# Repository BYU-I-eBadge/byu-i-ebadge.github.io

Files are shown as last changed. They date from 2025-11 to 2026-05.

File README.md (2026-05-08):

# BYU-I e-Badge Project
Github Pages for the BYU-I e-Badge Project

[e-Badge Project Repository](https://github.com/BYU-I-eBadge/e-badge)
- [e-Badge Pinouts](https://github.com/BYU-I-eBadge/e-badge/blob/main/docs/Pinout.md)

[Minibadge Project Repository](https://github.com/BYU-I-eBadge/minibadge)

## Tutorials:
## WebFlasher:
This allows flashing the board directly from a webpage:
- [WebFlash](https://byu-i-ebadge.github.io/namebadge-webflash/)

### Minibadge Tutorials:
- [LED Tutorial](/minibadge_tutorial/tutorial)
- [I2C Tutorial](/minibadge_tutorial_i2c/tutorial) (Todo)
- [Old Tutorial](/minibadge_tutorial_old/tutorial)

#### Tutorial Minibadges:
- [Example Minibadges](https://github.com/BYU-I-eBadge/byu-i-ebadge.github.io/tree/main/minibadge_examples/)
    - [LED Tutorial Minibadge](https://github.com/BYU-I-eBadge/byu-i-ebadge.github.io/tree/main/minibadge_examples/LED)
    - [I2C Tutorial Minibadge](https://github.com/BYU-I-eBadge/byu-i-ebadge.github.io/tree/main/minibadge_examples/I2C)

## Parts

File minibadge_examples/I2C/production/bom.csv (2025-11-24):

Designator | Footprint | Quantity | Value | LCSC Part #
MB1 | MiniBadge_Full | 1 | MiniBadge_Full
U1 | DIP-8_L10.0-W6.5-P2.54-LS7.6-BL-A | 1 | AT24C02C-PUM | C8810

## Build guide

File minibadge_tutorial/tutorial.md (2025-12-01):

# Minibadge Tutorial

This tutorial is designed for KiCad 9.0.4.
Download the latest version of KiCad from [kicad.org](https://www.kicad.org/download/).
A KiCad configuration with metric unit settings is assumed.

## Download Minibadge Symbols and Footprints

The Minibadge follows a standard which can be accessed as a set of KiCad libraries for footprints and schematics.

To obtain the files necessary to build your Minibadge, navigate to [github.com/BYU-I-eBadge/minibadge/releases](https://github.com/BYU-I-eBadge/minibadge/releases).

The KiCad symbol and footprint variants can be found on the releases page. On the latest release[^1], download `minibadge_full.kicad_sym` and `MiniBadge_Full.kicad_mod` for this tutorial. Save these in a folder that can be navigated to later.

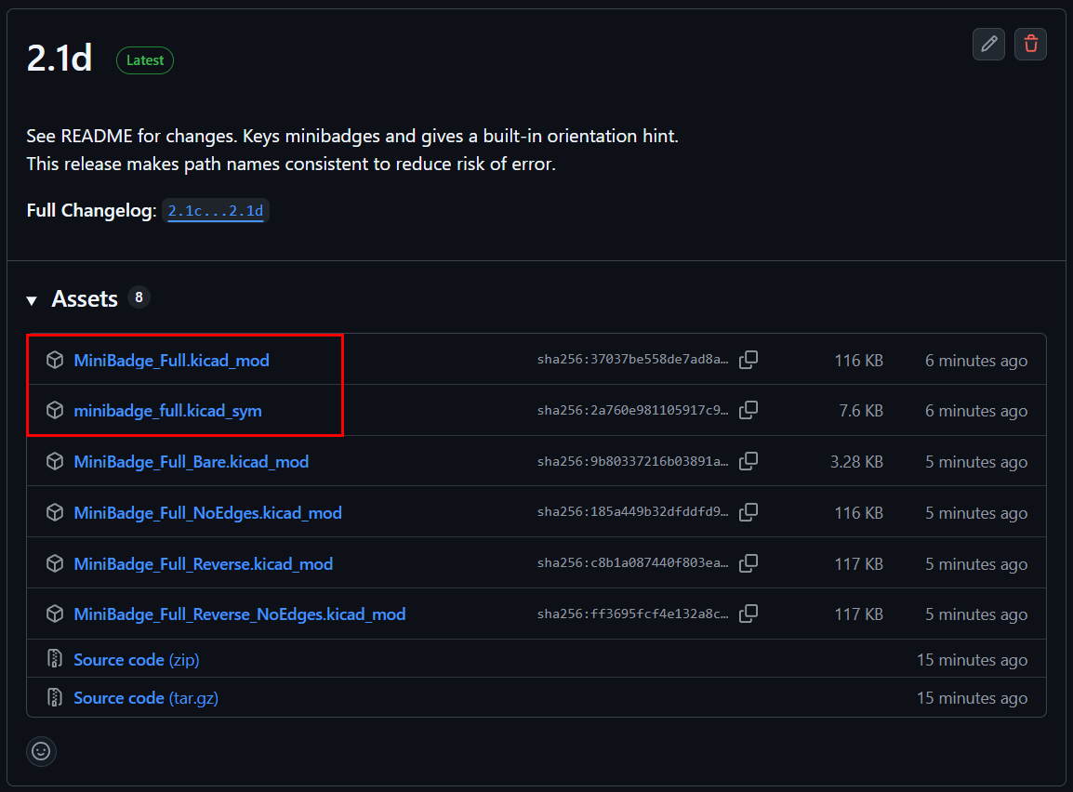
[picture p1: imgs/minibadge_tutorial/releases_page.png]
minibadge release


## Design in KiCad

### Initial Project Setup

Make and open a new project in KiCad. Save it in a directory of your choice. Feel free to name the project something memorable.

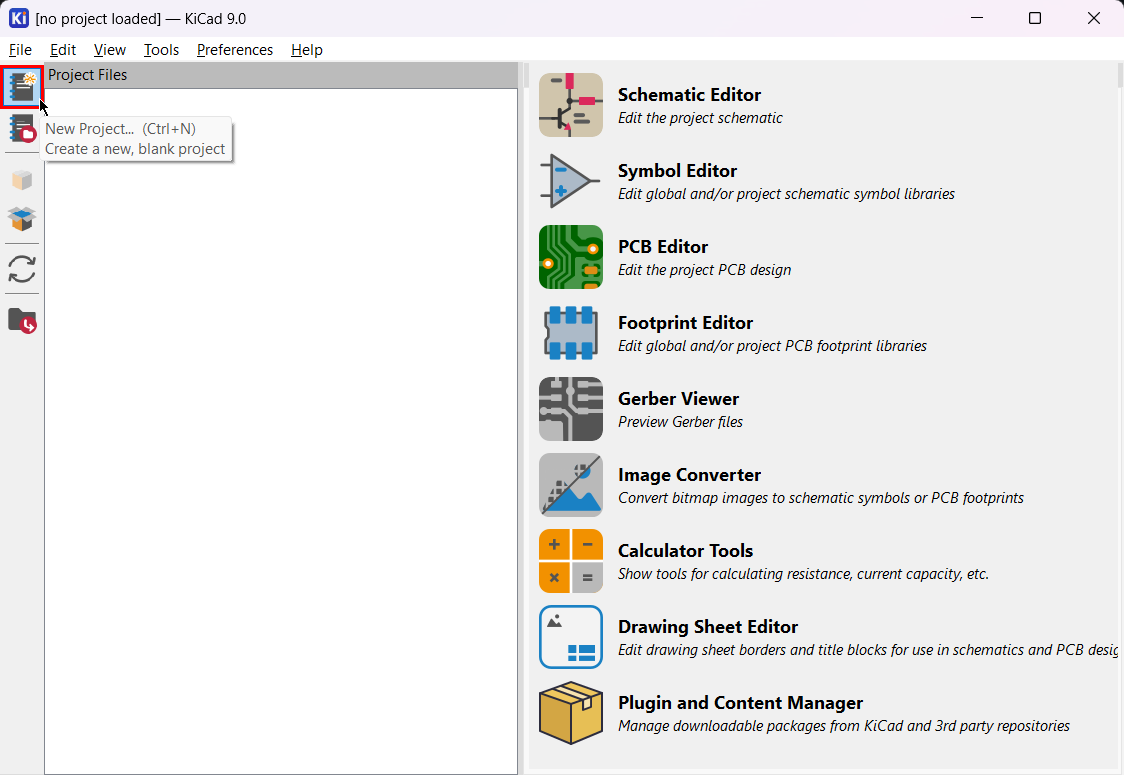
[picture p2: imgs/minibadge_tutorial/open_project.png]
hint make new project


After making your project, the window should now look something like this:

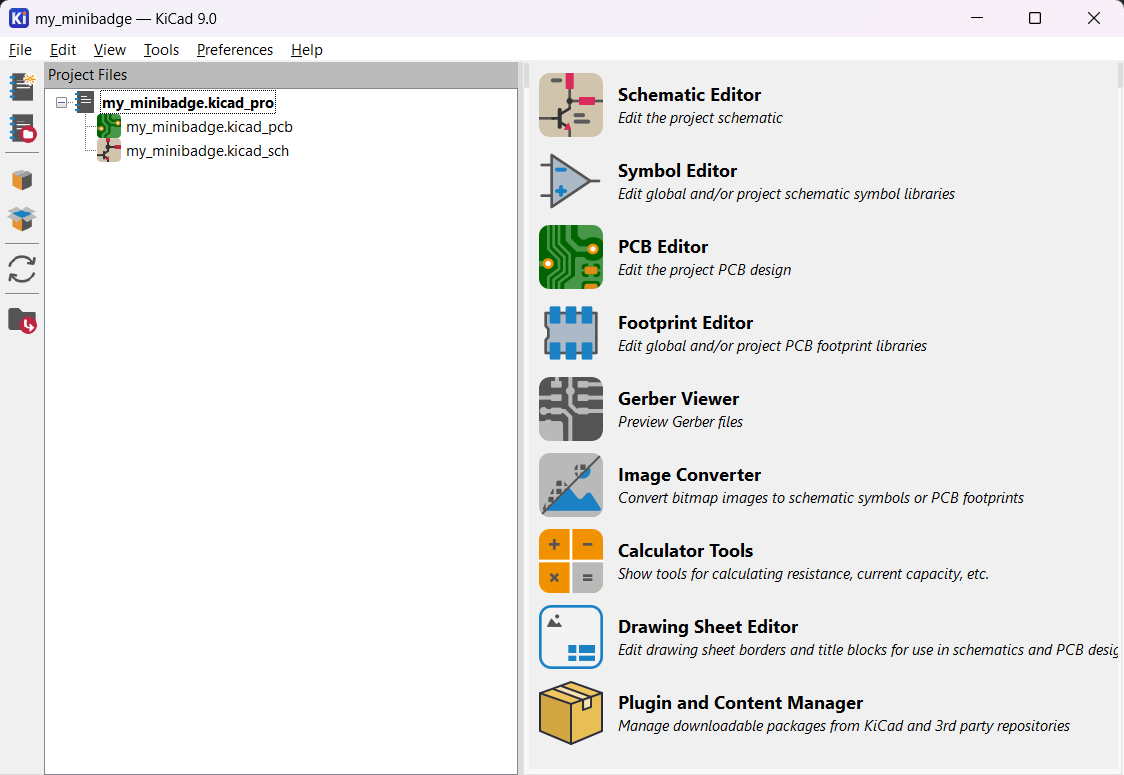
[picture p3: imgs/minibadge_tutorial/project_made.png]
created project


Now that the project has been made, the symbol and footprint need to be added so they are accessible from library browsers. Move the downloaded files into your project folder or somewhere easily accessible.

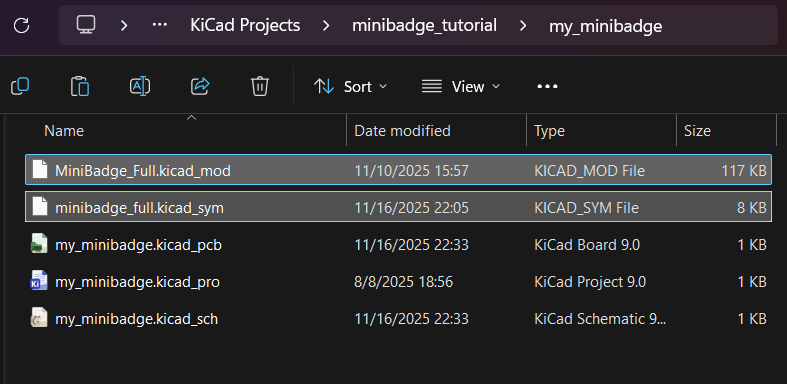
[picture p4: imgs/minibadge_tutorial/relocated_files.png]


Navigate to `Preferences` on the toolbar.

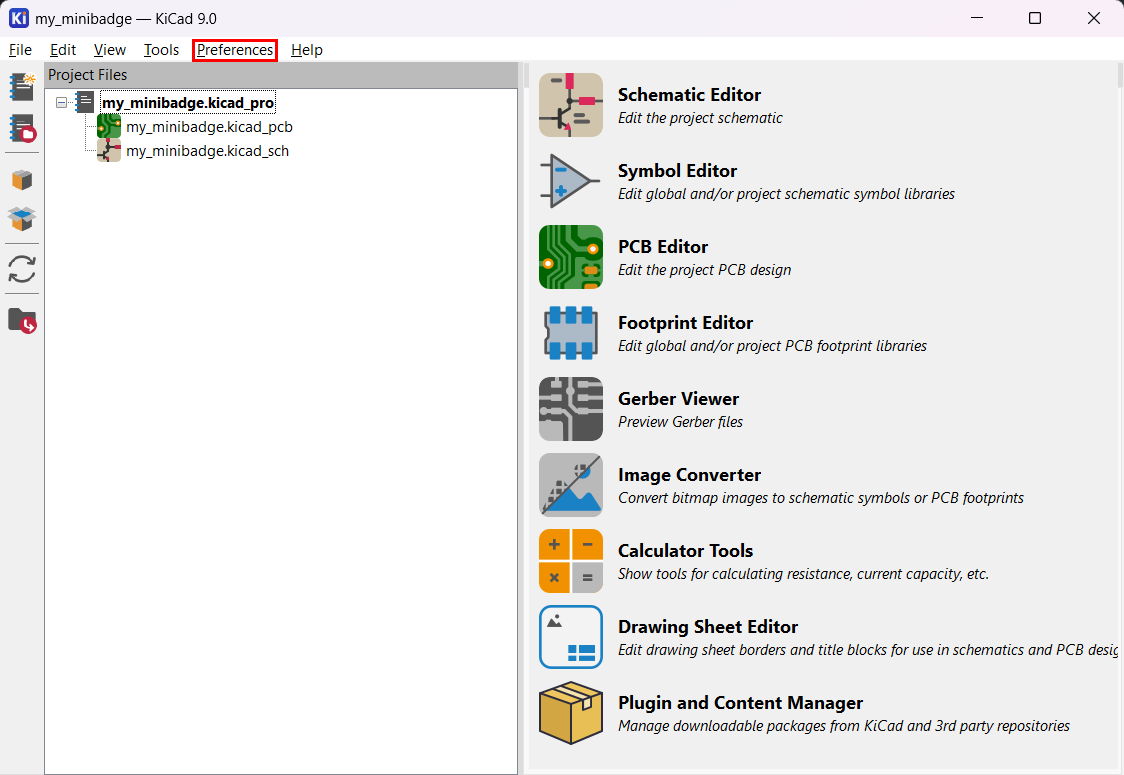
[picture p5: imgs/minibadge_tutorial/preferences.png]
go to preferences


Then, go to `Manage Symbol Libraries`.

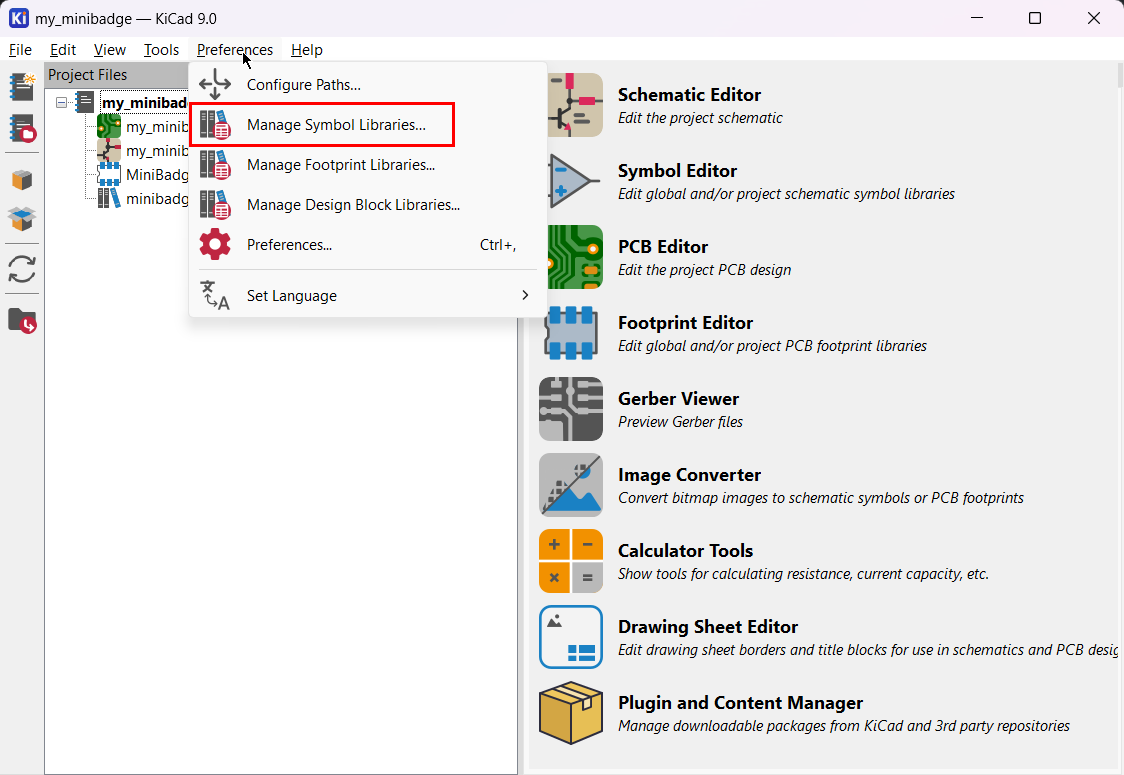
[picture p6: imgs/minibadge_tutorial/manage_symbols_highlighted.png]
go to manage symbol libraries


A new window will appear. Navigate to the `Project Specific Libraries` tab to add the Minibadge symbol to this project only.

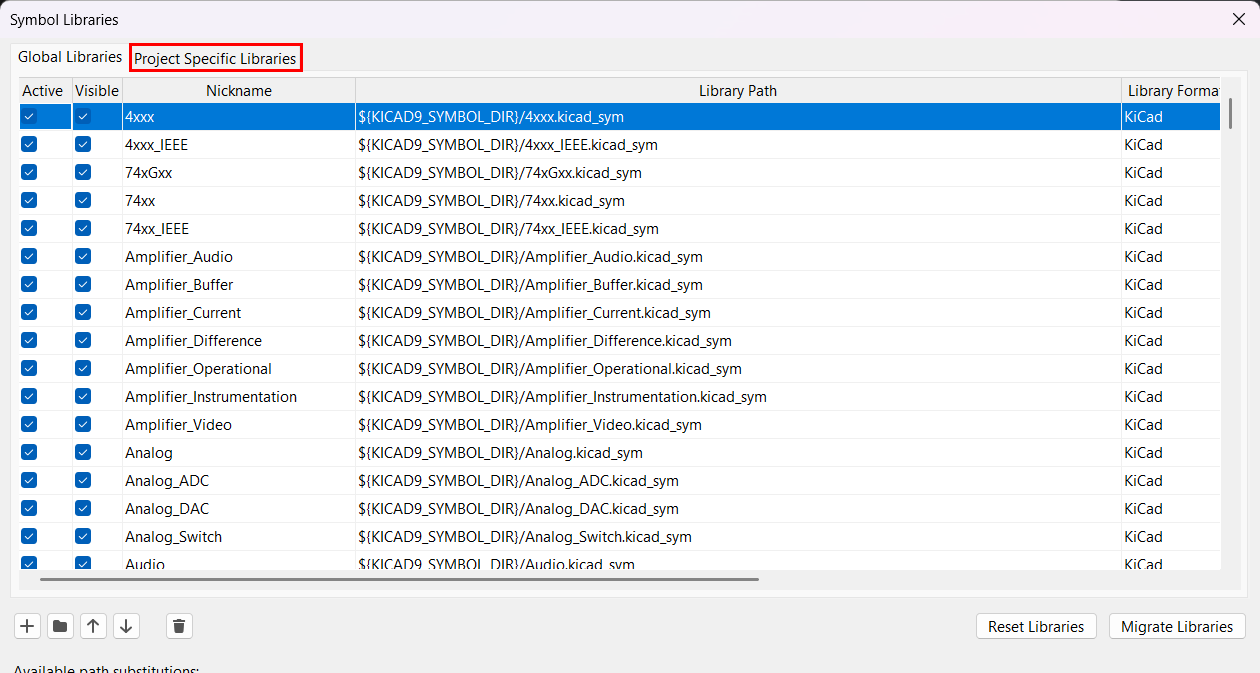
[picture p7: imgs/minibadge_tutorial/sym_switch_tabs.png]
switch tabs


Once switched to the correct tab, click the button with the folder icon to open the downloaded symbol library.
**For KiCad symbols, open the `*.kicad_sym` file to add the library.**

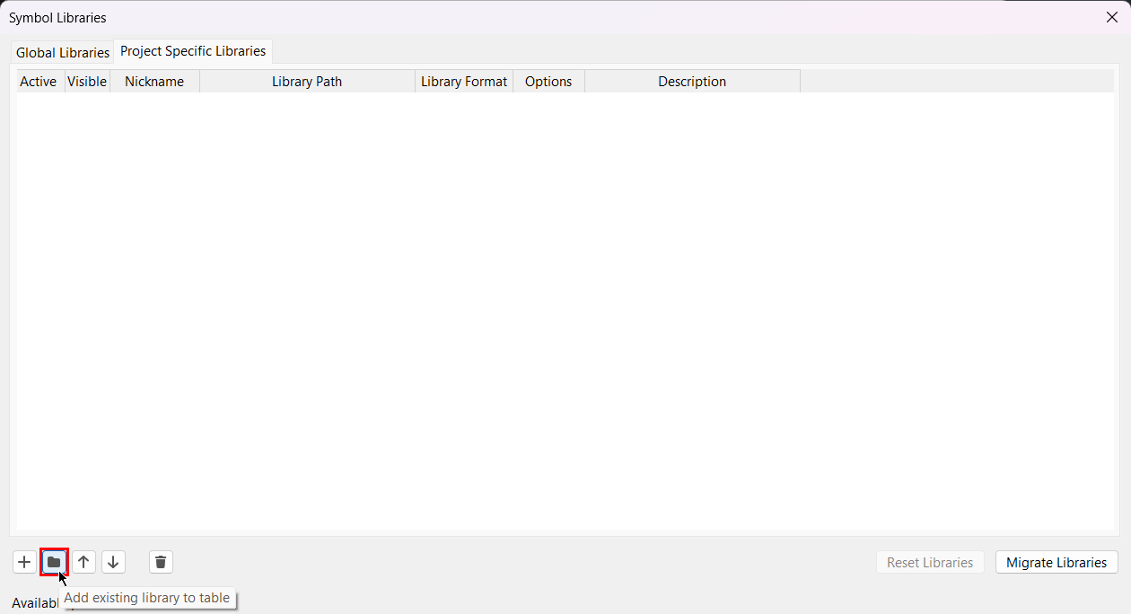
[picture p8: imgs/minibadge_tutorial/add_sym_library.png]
add symbol library button


Select the `minibadge_full.kicad_sym` file from the folder it was stored in and open it.

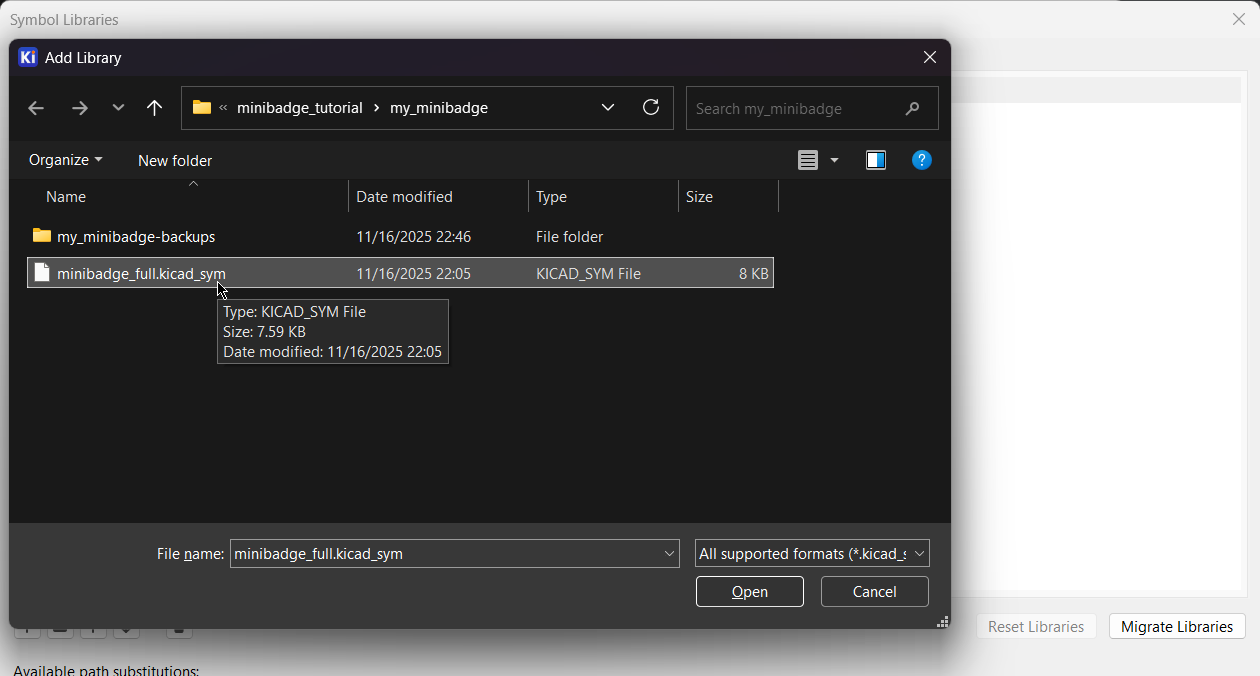
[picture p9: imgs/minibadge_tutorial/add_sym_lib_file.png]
add symbol library file


Next, to avoid any pathing related errors, rename the library Nickname from "minibadge_full" to "Minibadge" (case-sensitive).

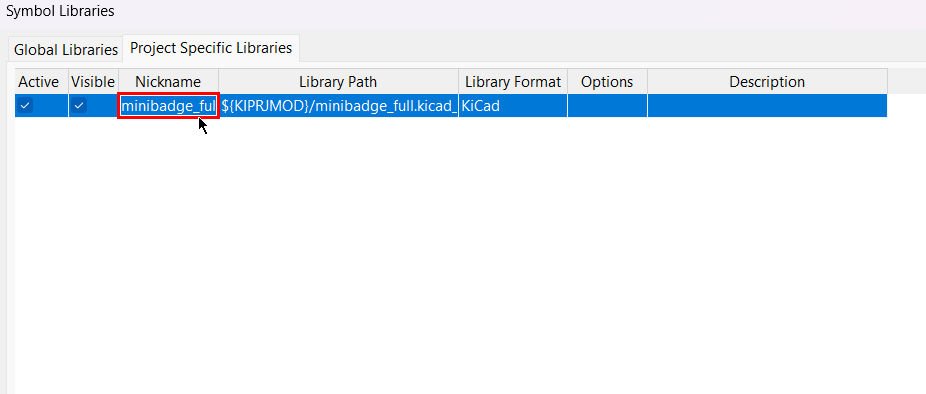
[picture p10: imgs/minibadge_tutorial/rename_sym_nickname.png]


The Symbols Library Window should now look something like this:

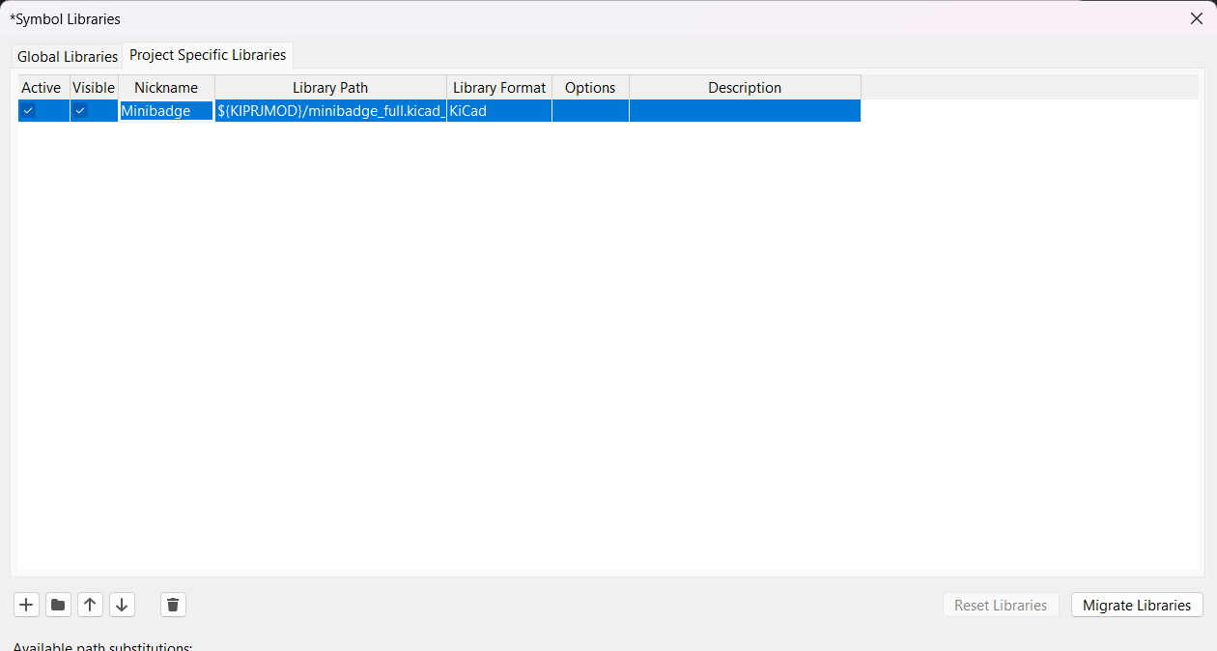
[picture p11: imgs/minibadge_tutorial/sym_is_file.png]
point out symbol libraries are files


Press OK to save changes and close the window for managing symbol libraries. It may take a moment for the library to load into the project.

In preferences again, navigate to manage footprint libraries.

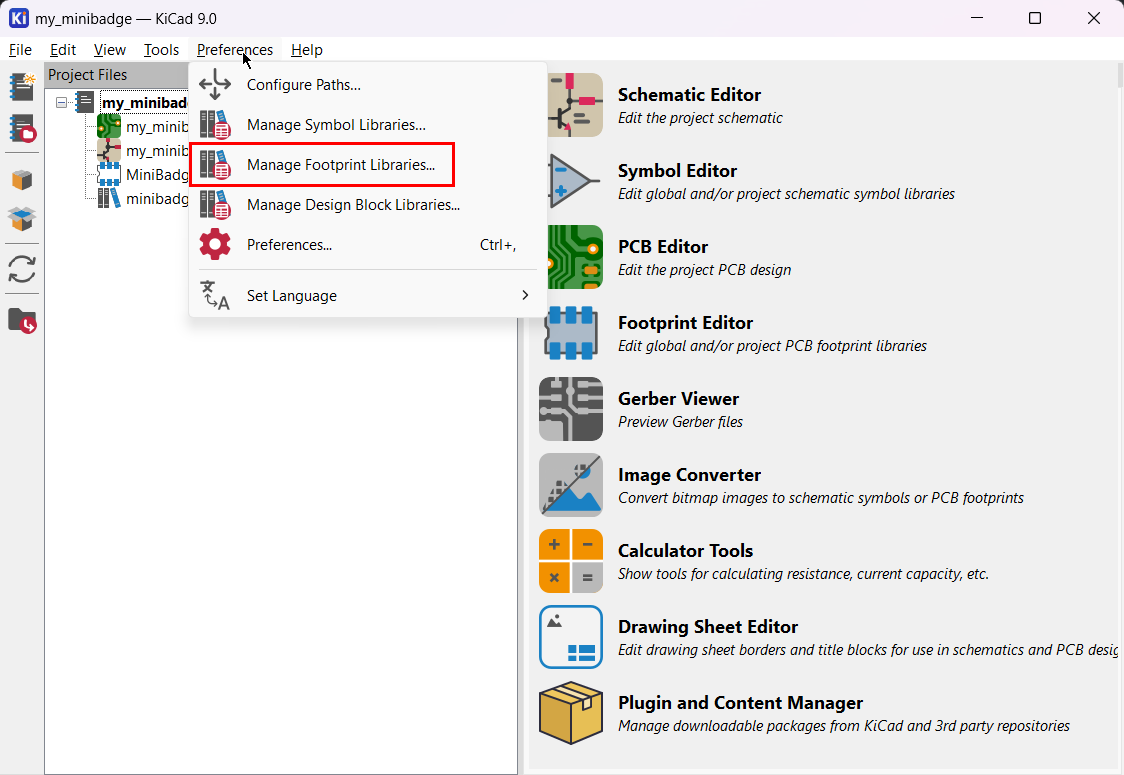
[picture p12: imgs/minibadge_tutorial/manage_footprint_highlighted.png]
go to manage footprint libraries


Similar to the window for managing symbol libraries, navigate to the `Project Specific Libraries` tab.
Click the button with the folder icon to open the downloaded footprint library.
**For KiCad footprints, open the folder that contains `*.kicad_mod` file(s) to add the library. This can reside in the same directory as your symbol library and other files; KiCad will only inventory the `*.kicad_mod` files from the selected folder.**

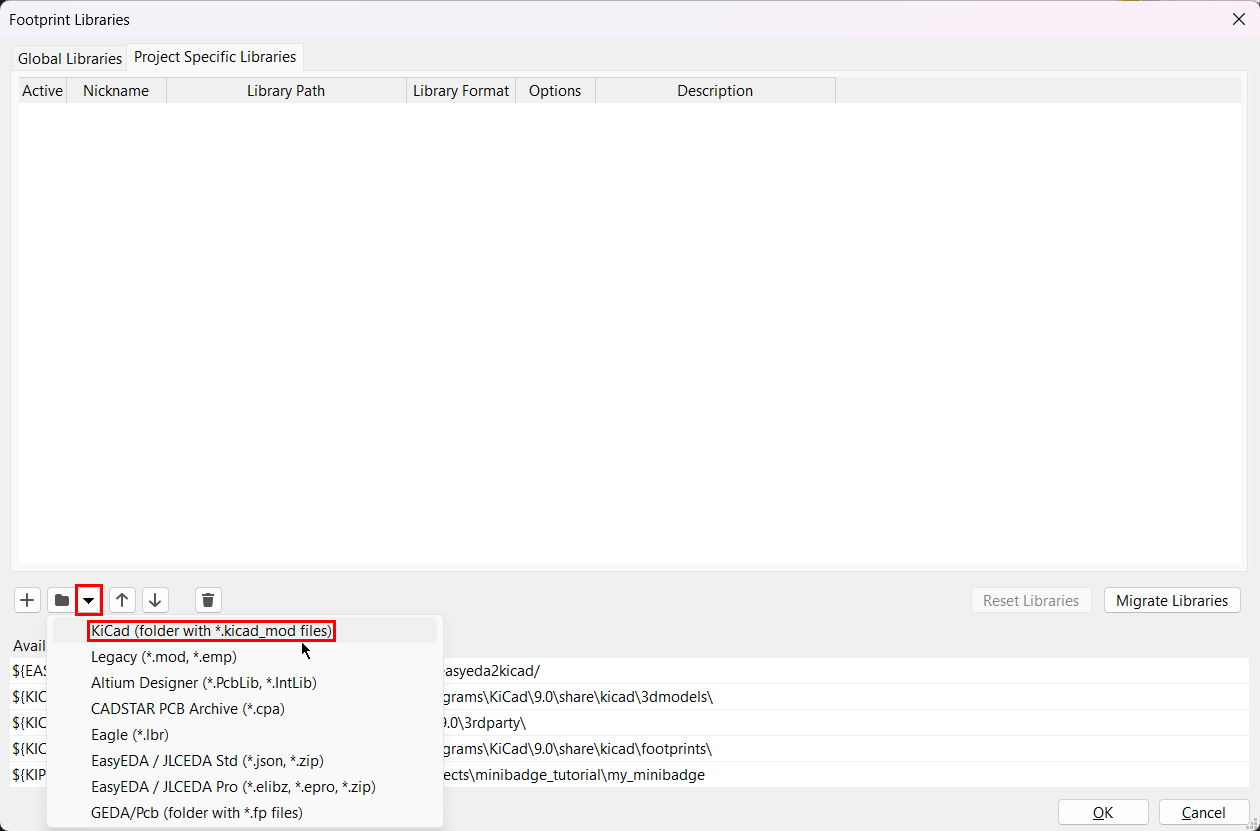
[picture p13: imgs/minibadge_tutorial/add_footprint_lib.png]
add footprint library button


Navigate to the folder which contains the `MiniBadge_Full.kicad_mod` file and click on the "Select Folder" button or any equivalent for your operating system.

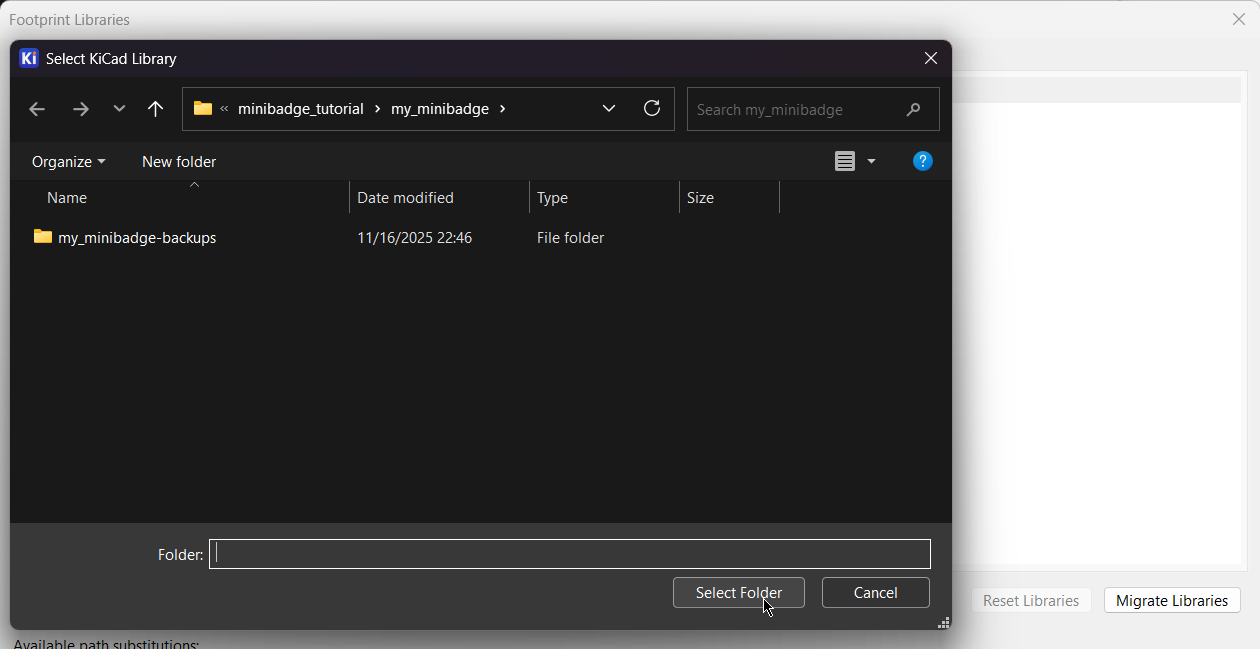
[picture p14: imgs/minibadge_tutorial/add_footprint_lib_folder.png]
add footprint library folder


Once again, change the Nickname to `Minibadge` (case-sensitive).

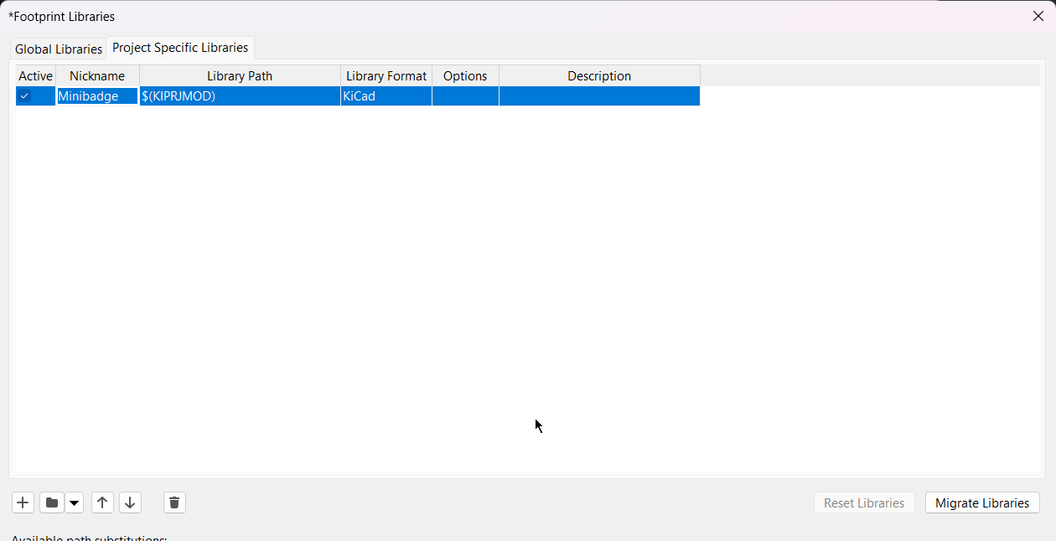
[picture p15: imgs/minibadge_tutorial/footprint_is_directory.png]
point out footprint libraries are folders


You can now press the OK button and return to the main project window.

### Schematic

Now we are ready to build the circuit with the installed libraries.

Enter the schematic editor by pressing the icon in the main window.

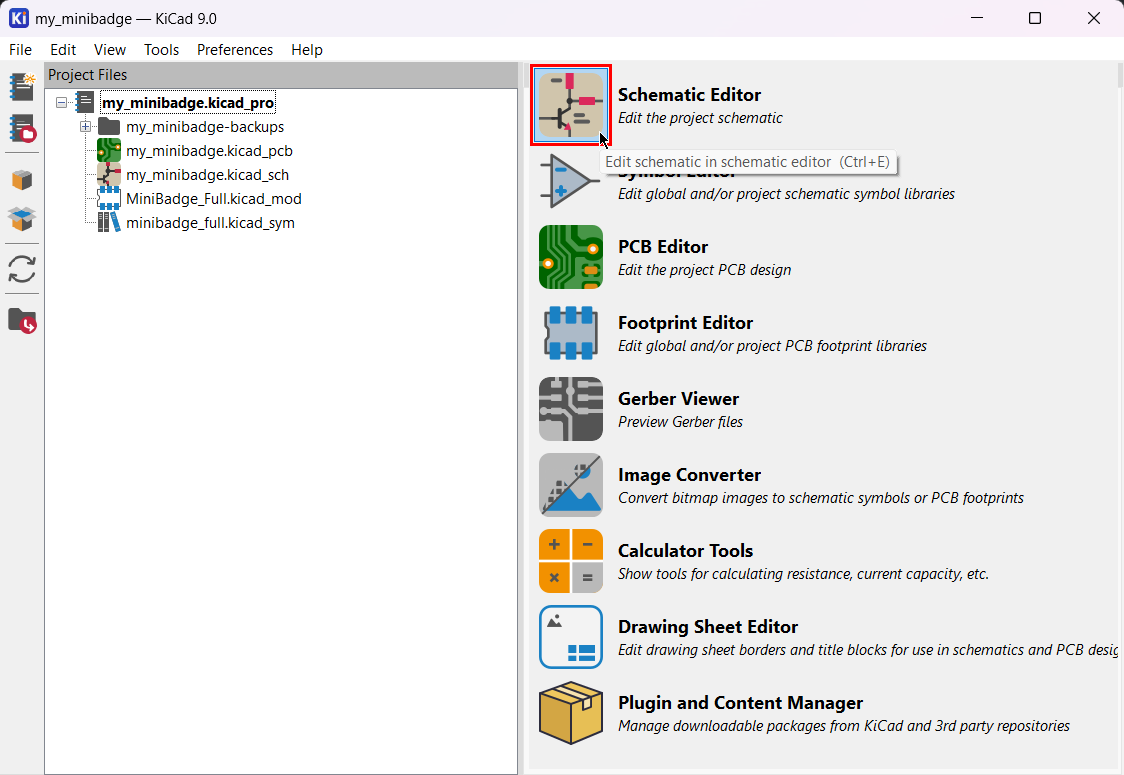
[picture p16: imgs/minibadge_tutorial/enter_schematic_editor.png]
hint enter schematic editor


A blank schematic will be shown. Start by placing symbols by pressing the highlighted icon or using the shortcut (A).

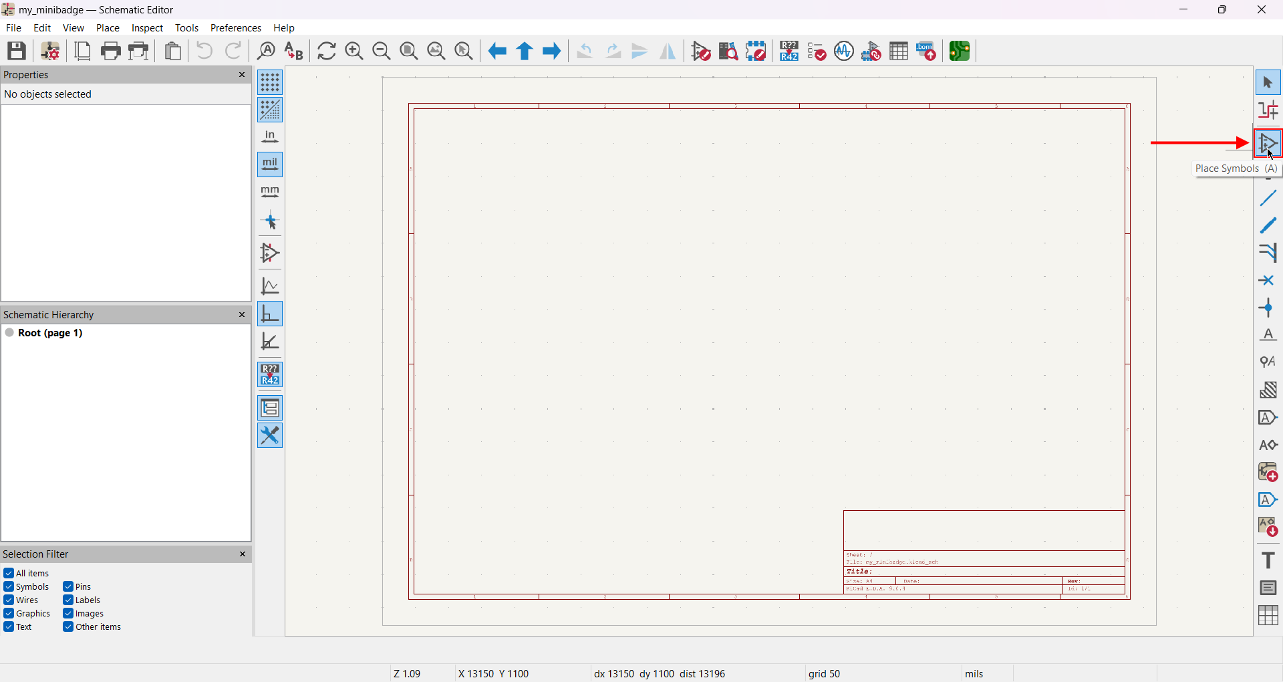
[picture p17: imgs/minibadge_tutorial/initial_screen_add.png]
initial screen hint add symbol


It may take a moment for the symbols to load. A new window will appear that will allow for selecting symbols for components.
Search for the minibadge symbol that was downloaded. Select the one that looks like the one pictured, and press OK to close the window.

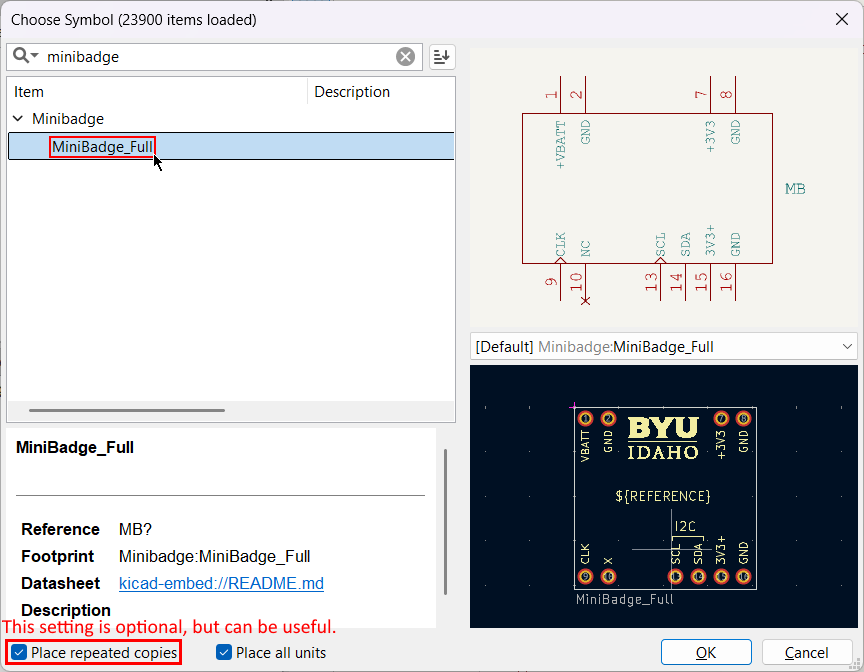
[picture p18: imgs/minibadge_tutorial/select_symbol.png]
select symbol window minibadge example


The symbol should appear attached to your cursor. Click to place the symbol. If the symbol still appears to follow your cursor after placement, press the ESC key to release your cursor; this is a side effect of having `Place repeated copies` selected.

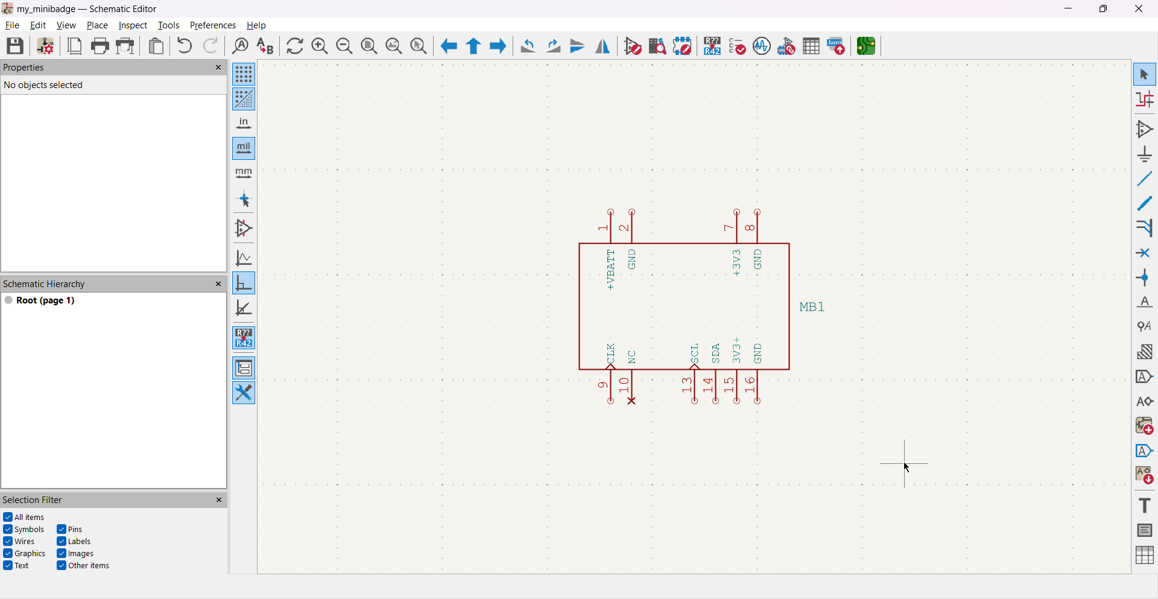
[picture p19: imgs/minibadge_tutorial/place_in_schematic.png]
symbol on schematic


For this tutorial, we will design a basic minibadge that has a simple LED circuit.
Add symbols for an LED and resistor to the schematic by following a process similar to placing the minibadge.

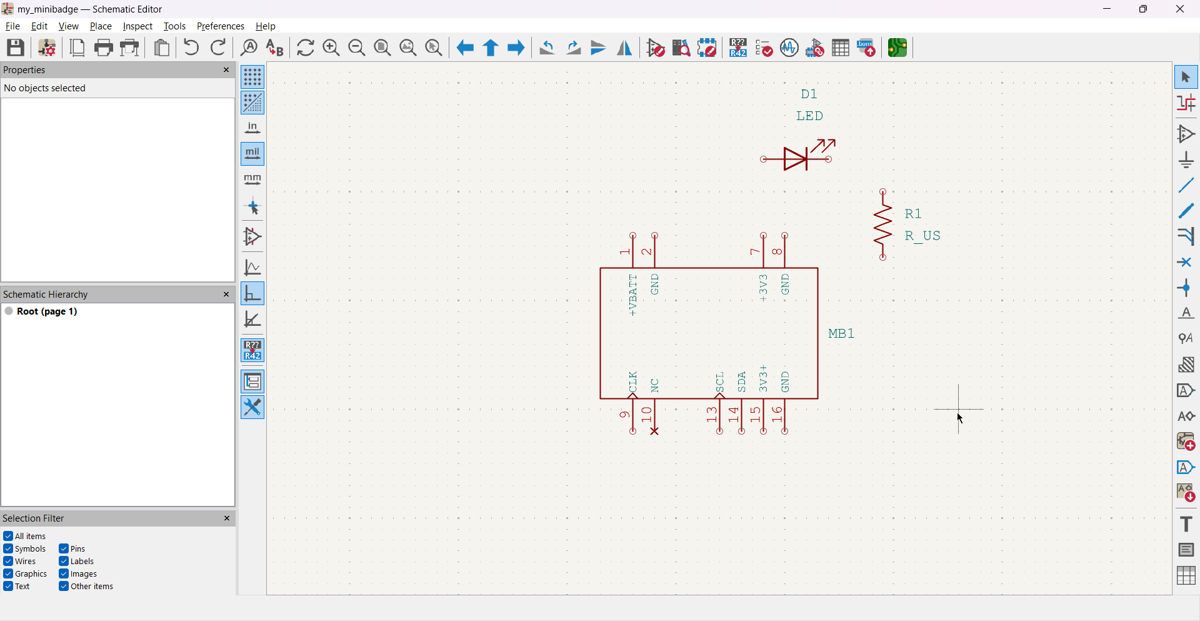
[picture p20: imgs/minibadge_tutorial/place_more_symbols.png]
add additional symbols


By double clicking on the resistor, the value can be changed. For this tutorial, the desired resistance is 100Ω, so in the "value" field, "R_US" can be replaced with 100ohm as shown below. Afterwards, press OK.

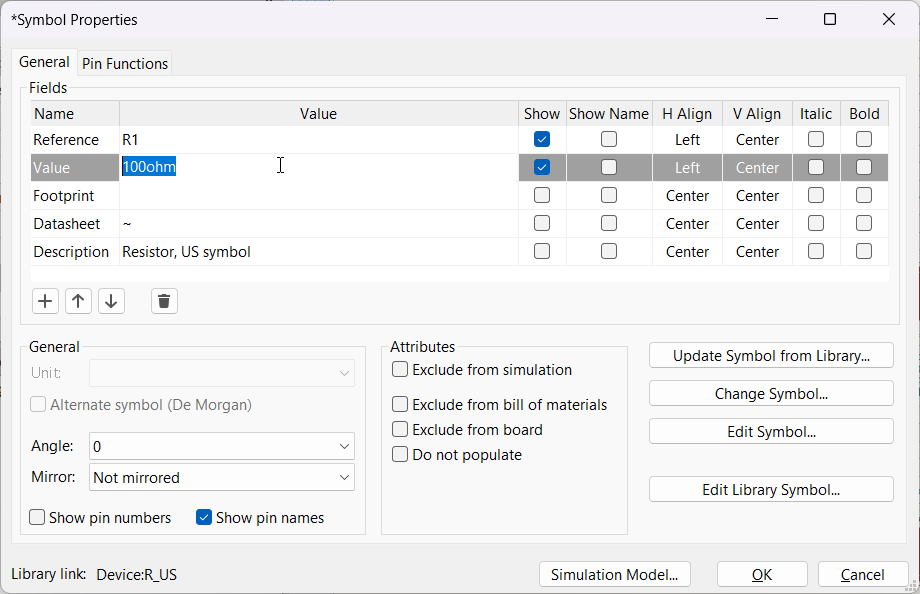
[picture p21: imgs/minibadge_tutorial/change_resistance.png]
change resistance


Now that all the symbols are placed, wires need to be added to connect the symbols together. To draw wires, press the highlighted wire button or press the (W) key.

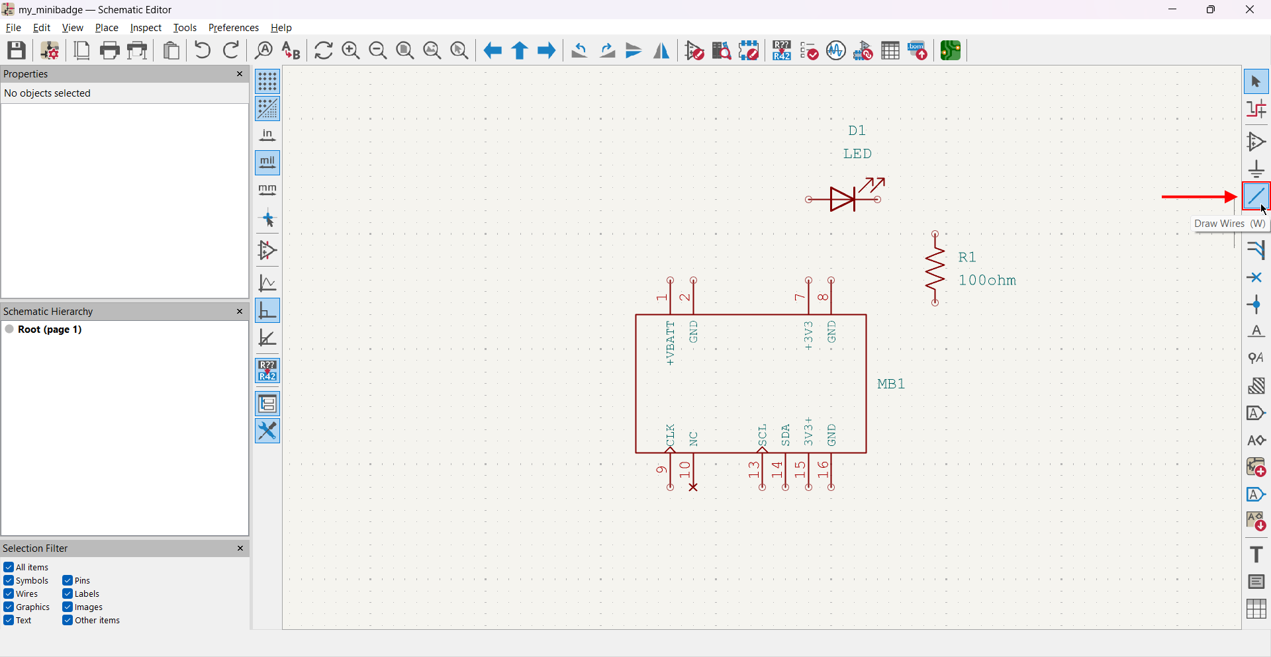
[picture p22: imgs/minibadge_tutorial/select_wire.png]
add wire


Wire the LED anode (the side with the triangle base) to any `+3V3` pin on the minibadge symbol.

Wire the LED cathode (the side with the flat line) to any side of R1.
Wire the unconnected side of R1 to any GND pin of the minibadge symbol.

**It is important that the circuit in your schematic is correct. It is easier to correct schematic issues before starting PCB design, rather than after.**

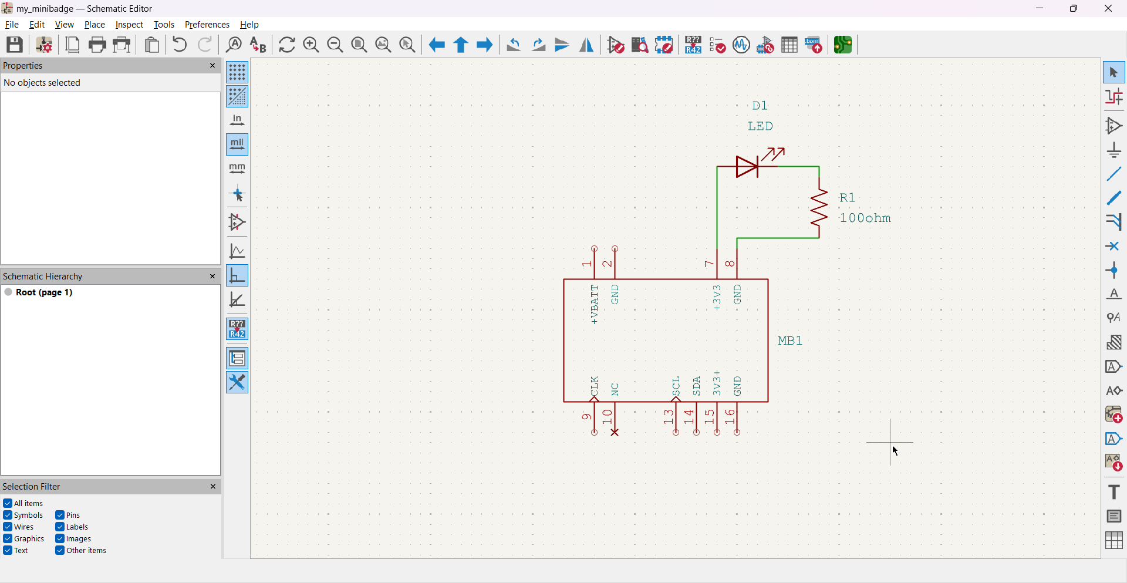
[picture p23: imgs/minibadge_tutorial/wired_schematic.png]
wired schematic


For completeness, the circuit should have its used power paths (3.3V, Ground) labeled and attached to the schematic.
Click on the icon to place power symbols or use the shortuct (P).

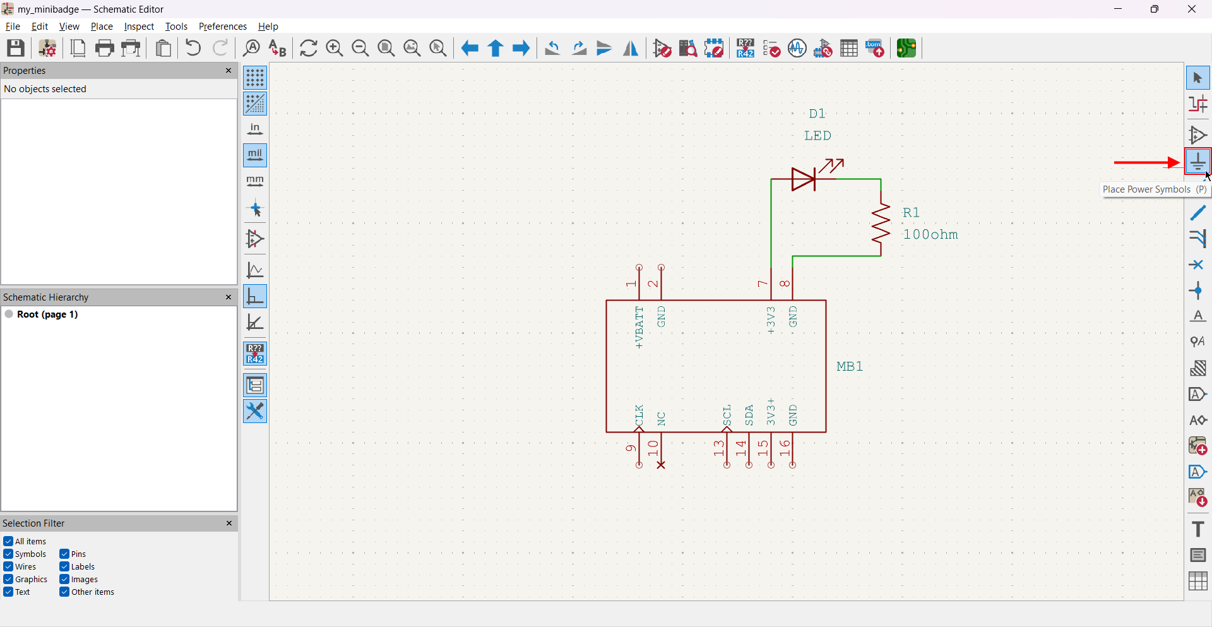
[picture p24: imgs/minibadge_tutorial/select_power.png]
add power symbols


A window will appear that operates identically to the window for picking component symbols.
For our ground (0V), use the `GND` symbol. Every pin that says `GND` on the minibadge should connect to one of these.

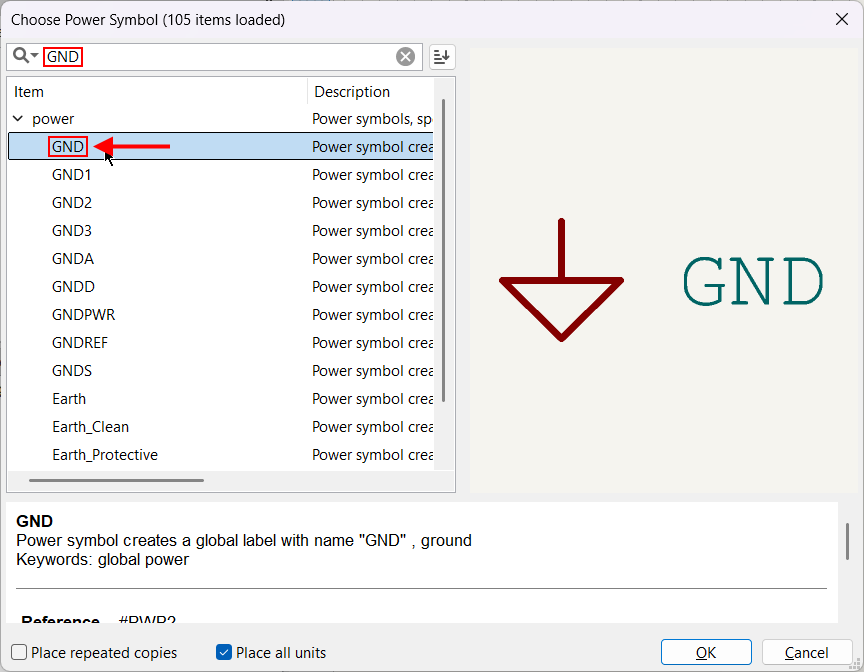
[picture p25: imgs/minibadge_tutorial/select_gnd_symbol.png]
select ground symbol window


Similarly, power symbols should be placed for 3.3V. These should go on the pins labelled `3V3+` and `+3V3`.

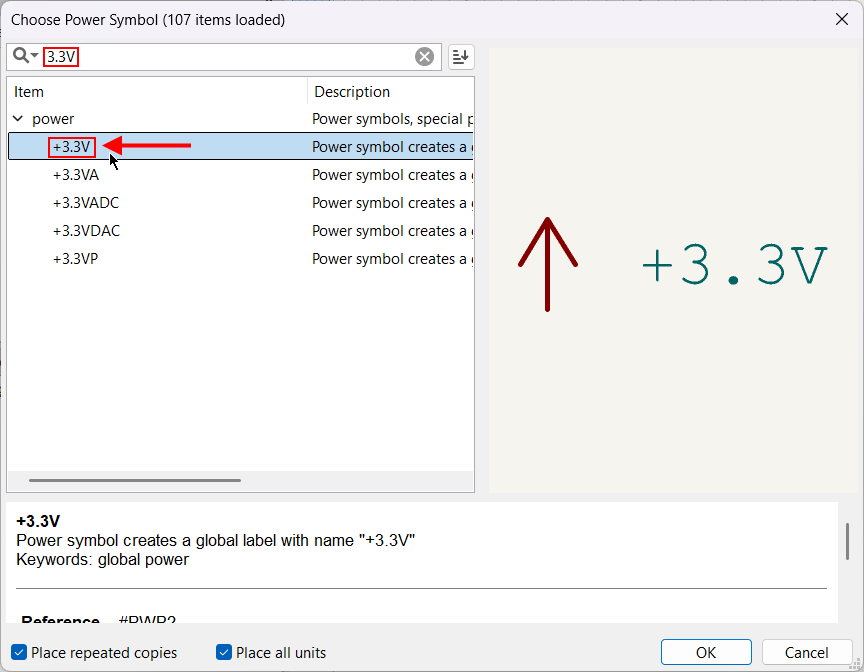
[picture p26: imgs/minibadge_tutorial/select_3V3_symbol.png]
select 3.3V symbol window


The schematic design is nearly complete. Click on the icon to place "no connect flags" on the remaining unused minibadge pins.

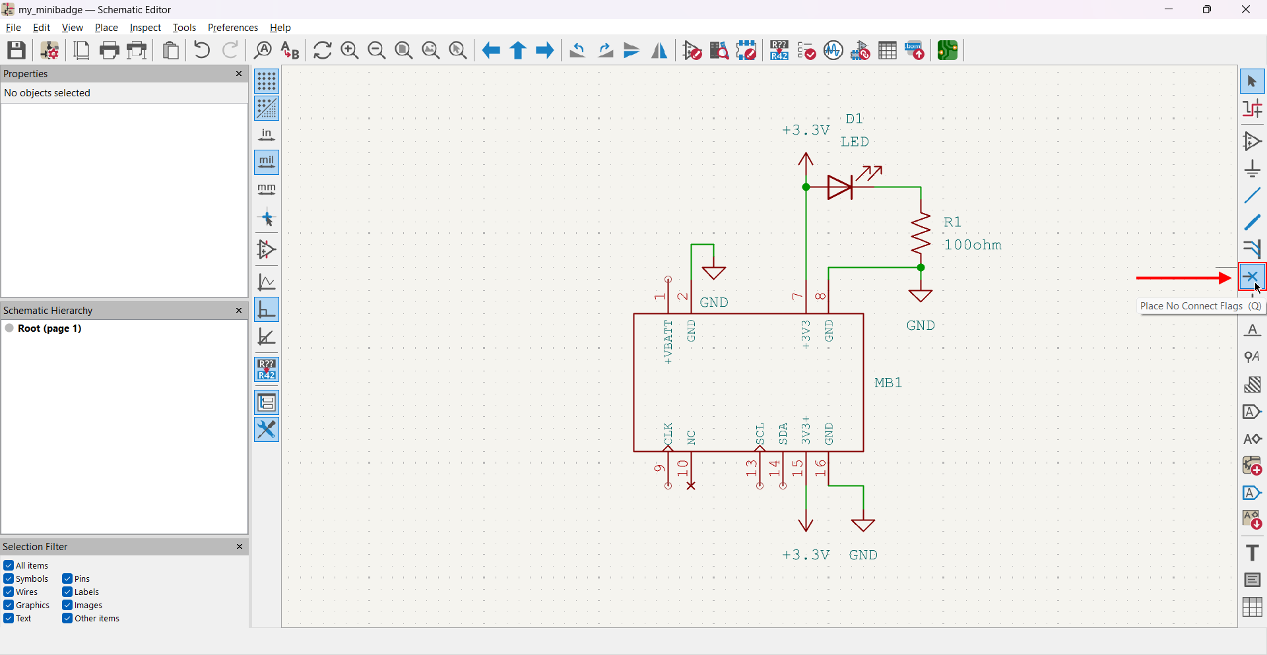
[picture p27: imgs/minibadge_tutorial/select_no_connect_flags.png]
select no connect flags


Your schematic should now resemble the following:

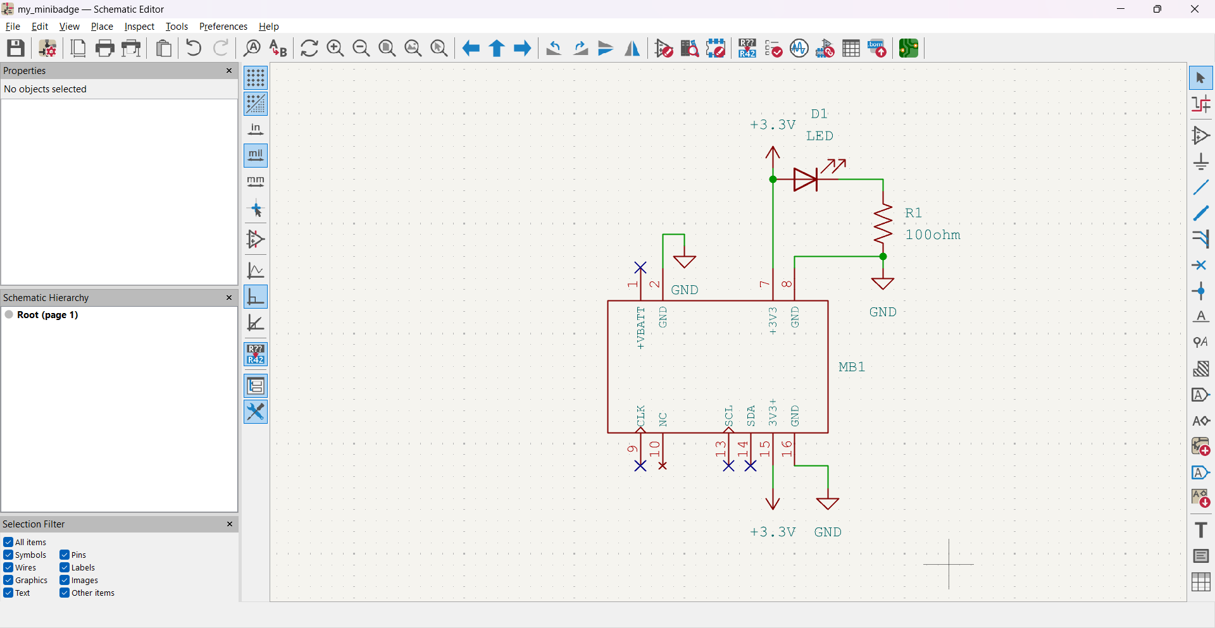
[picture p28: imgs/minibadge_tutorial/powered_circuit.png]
powered circuit


Annotate the schematic so that the design can be checked for errors and be imported to the PCB editor.

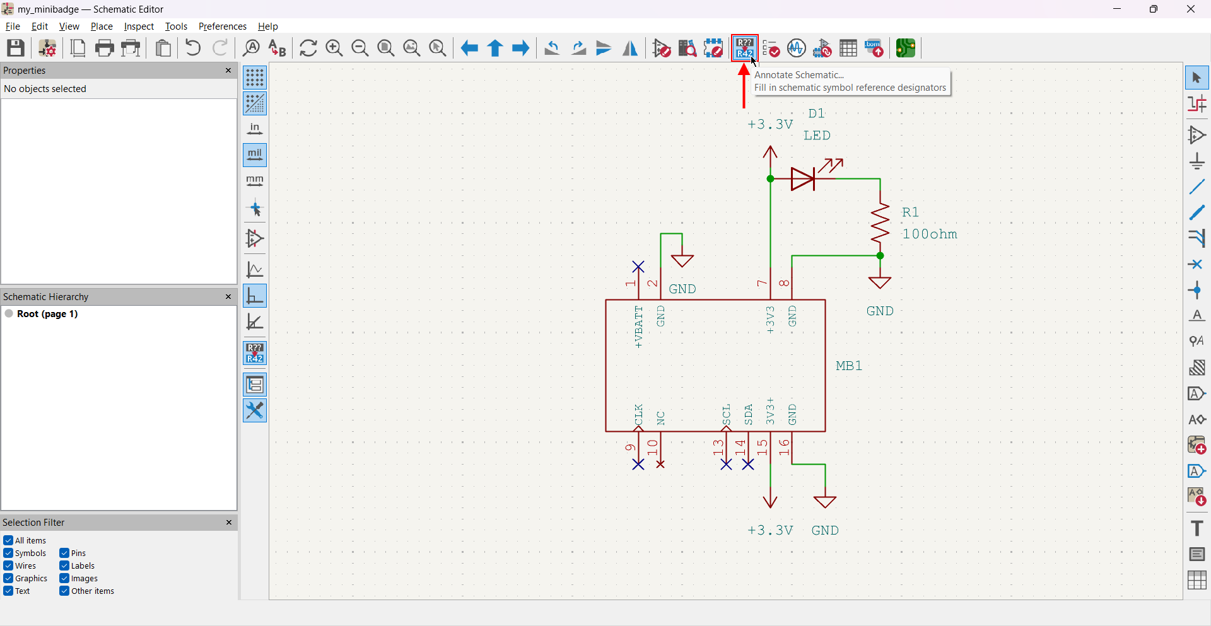
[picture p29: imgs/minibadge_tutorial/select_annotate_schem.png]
select annotate schematic


Click `Annotate` on the window that appears. The default settings in this window should work for this design.
**Note that this overwrites all reference designators. This may not be ideal for different designs.**

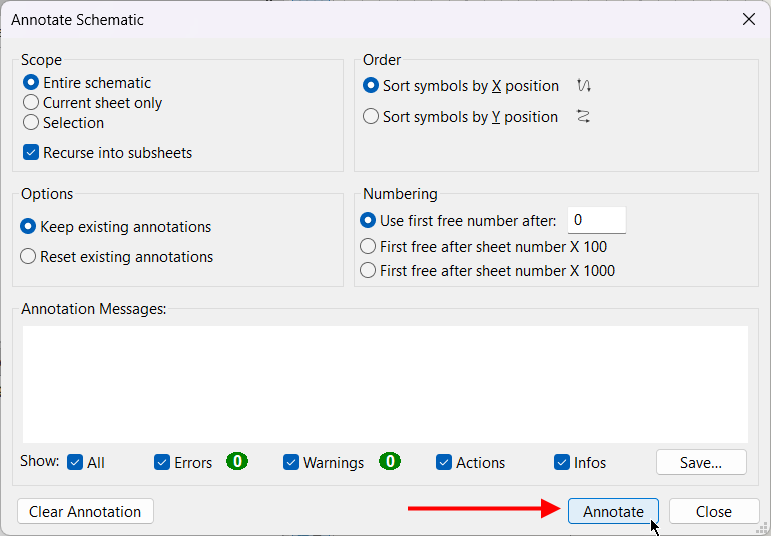
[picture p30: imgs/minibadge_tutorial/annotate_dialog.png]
annotate window


Now that the schematic is fully annotated, the Electrical Rules Checker (ERC) should now be run.

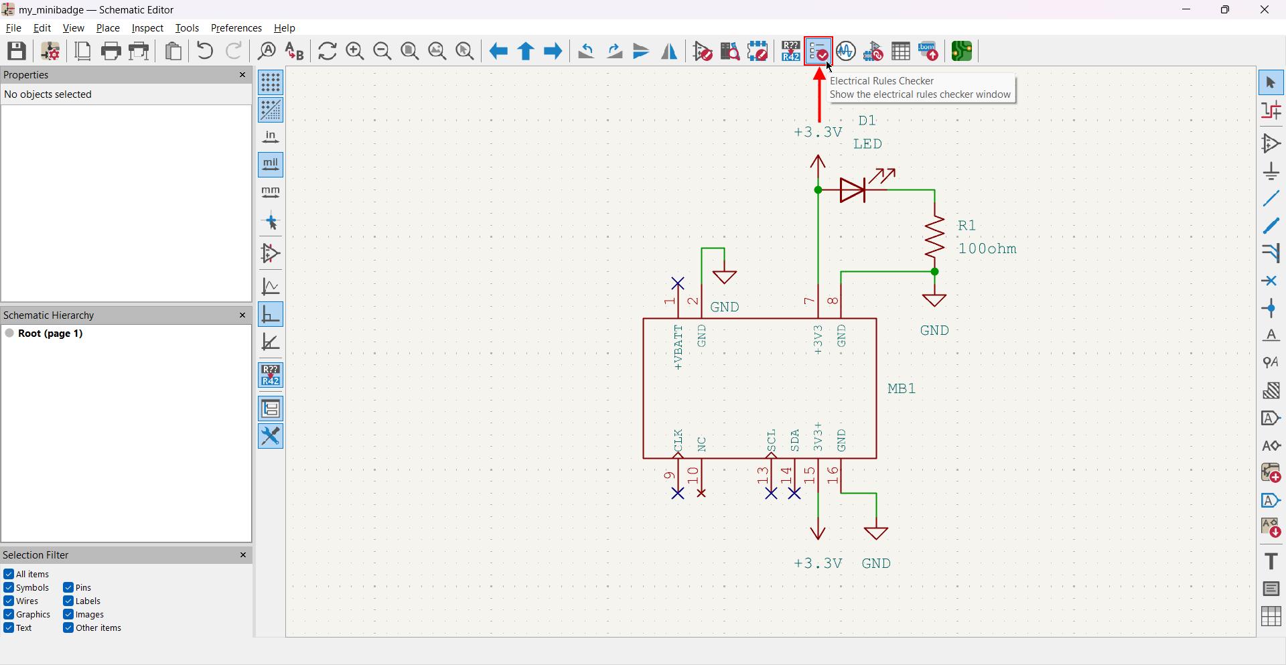
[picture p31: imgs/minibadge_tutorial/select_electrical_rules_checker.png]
select ERC


Click `Run ERC` on the window that appears.

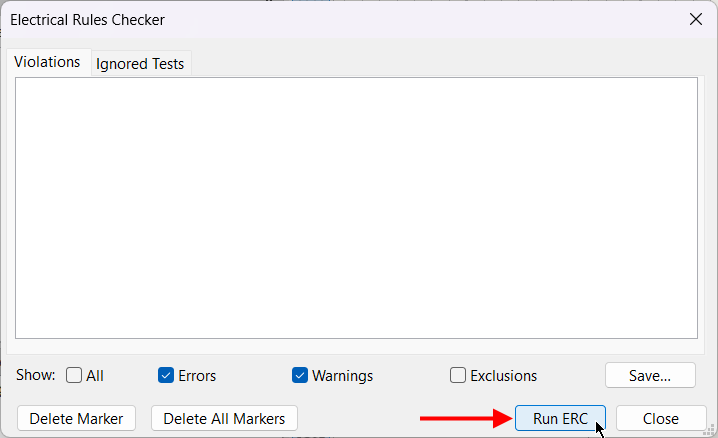
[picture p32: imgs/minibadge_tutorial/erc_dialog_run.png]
run ERC


With the current configuration in the schematic, there should be 2 errors and 0 warnings.
**If there are additional errors, it is likely there is an actual error in the design that needs troubleshooting.**

[^1]: *2025-12-01*. Latest minibadge version 2.1d at time of writing. KiCad Version 9.0.4.

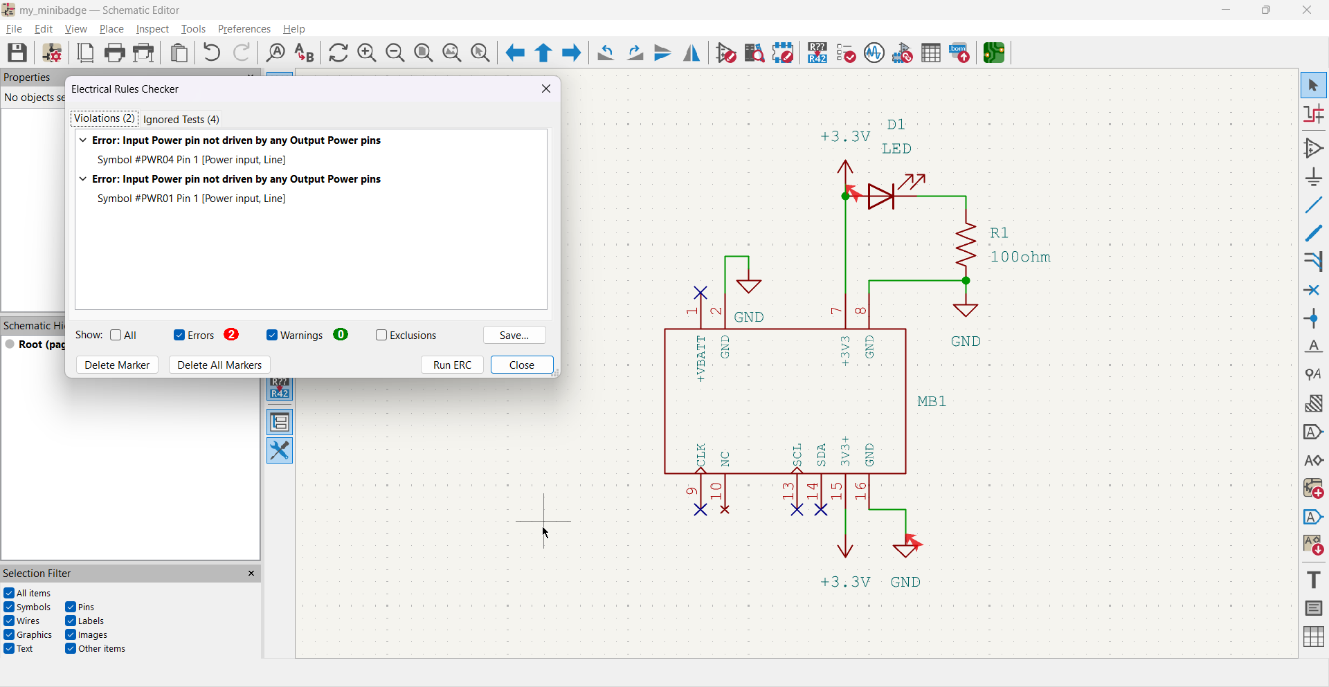
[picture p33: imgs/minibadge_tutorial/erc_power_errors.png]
ERC power errors


The reason why these errors occur is because the power symbols (`GND` and `+3.3V`) are technically undefined according to KiCad. To resolve this, we need to specify the power symbols by using a `PWR_FLAG` component.

Open the power symbols window, the same window which had the `GND` and `+3.3V` symbols, and find the `PWR_FLAG` symbol and place it in the schematic.

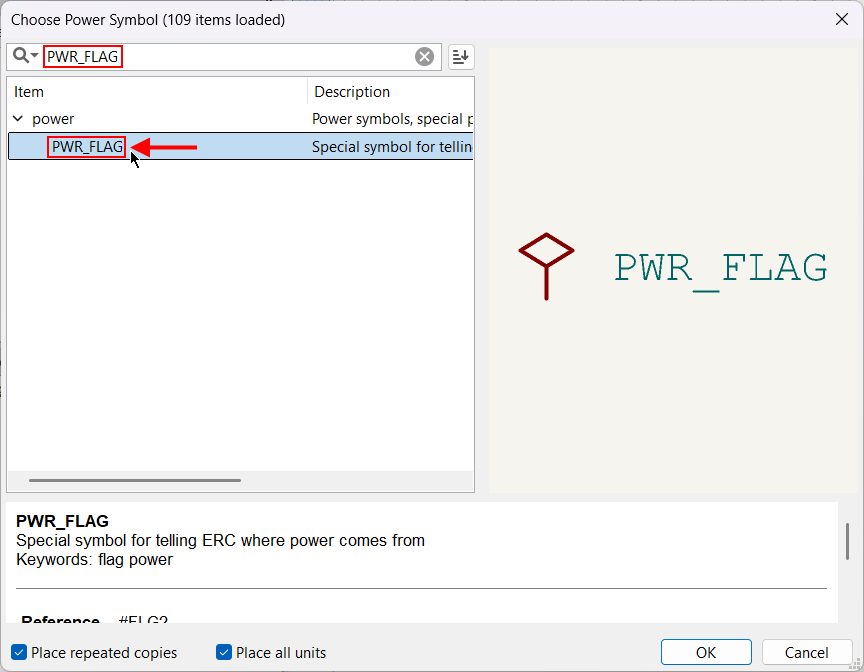
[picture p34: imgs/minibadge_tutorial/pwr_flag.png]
power flag symbol


Now, place two `PWR_FLAG` symbols, one for `GND`, and one for `+3.3V`. Next, connect a `GND` symbol to one and a `+3.3V` symbol to the other.

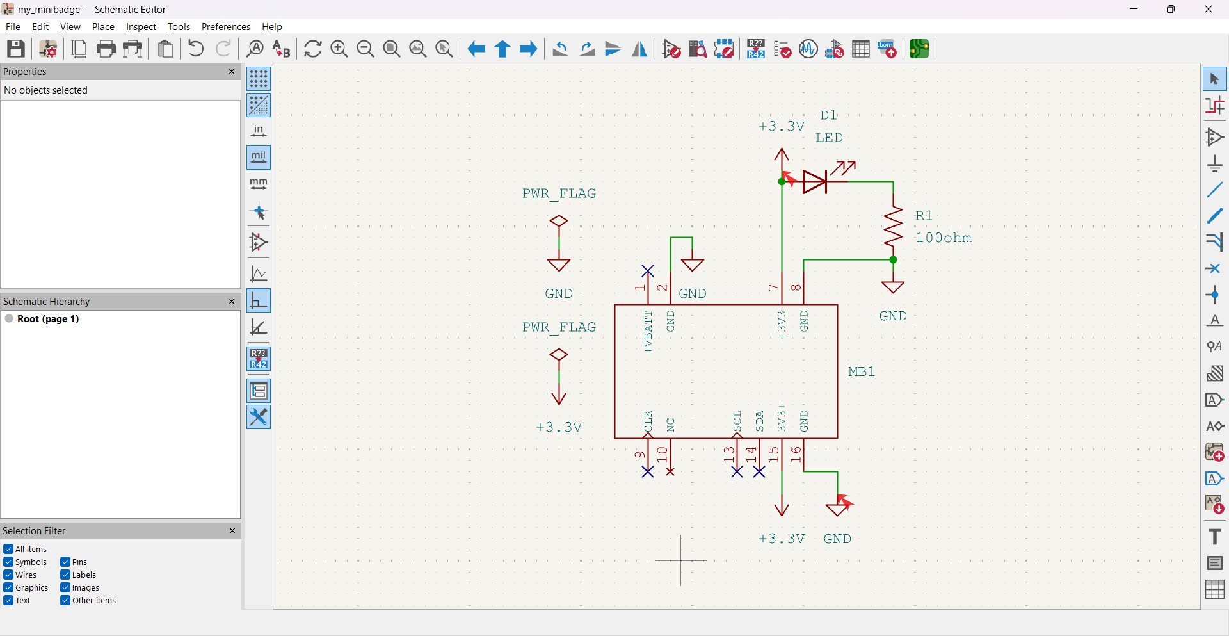
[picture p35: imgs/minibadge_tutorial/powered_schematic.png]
power defined schematic


Rerun the ERC to verify that there are no additional errors.

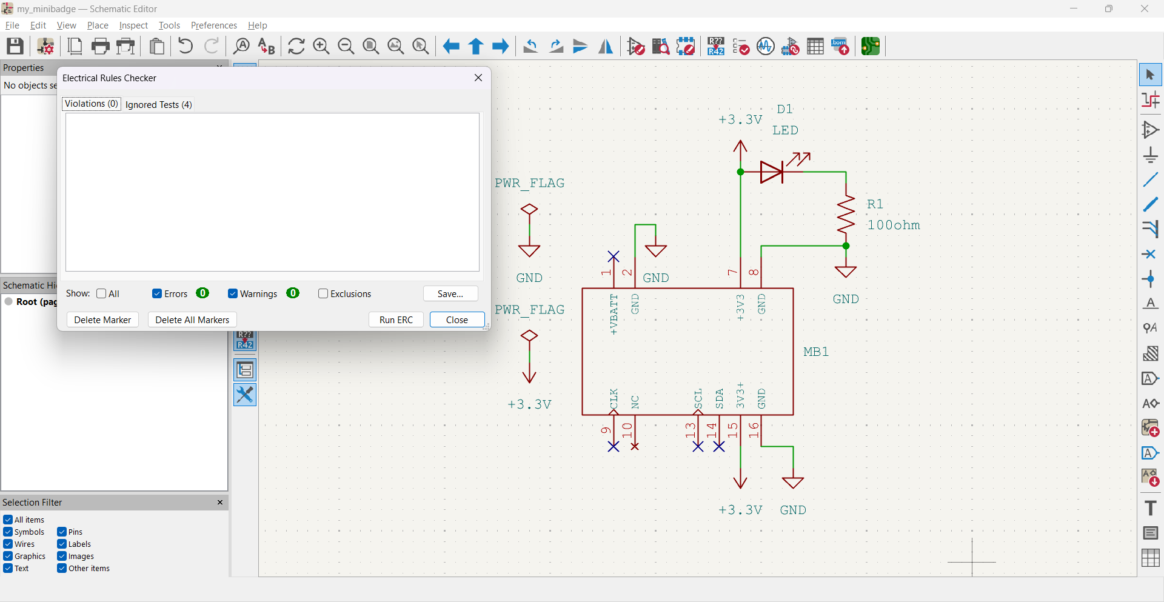
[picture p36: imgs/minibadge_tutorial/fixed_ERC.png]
fixed ERC


After verifying the the design is electrically sound, click the icon to assign footprints to all symbols in the schematic.

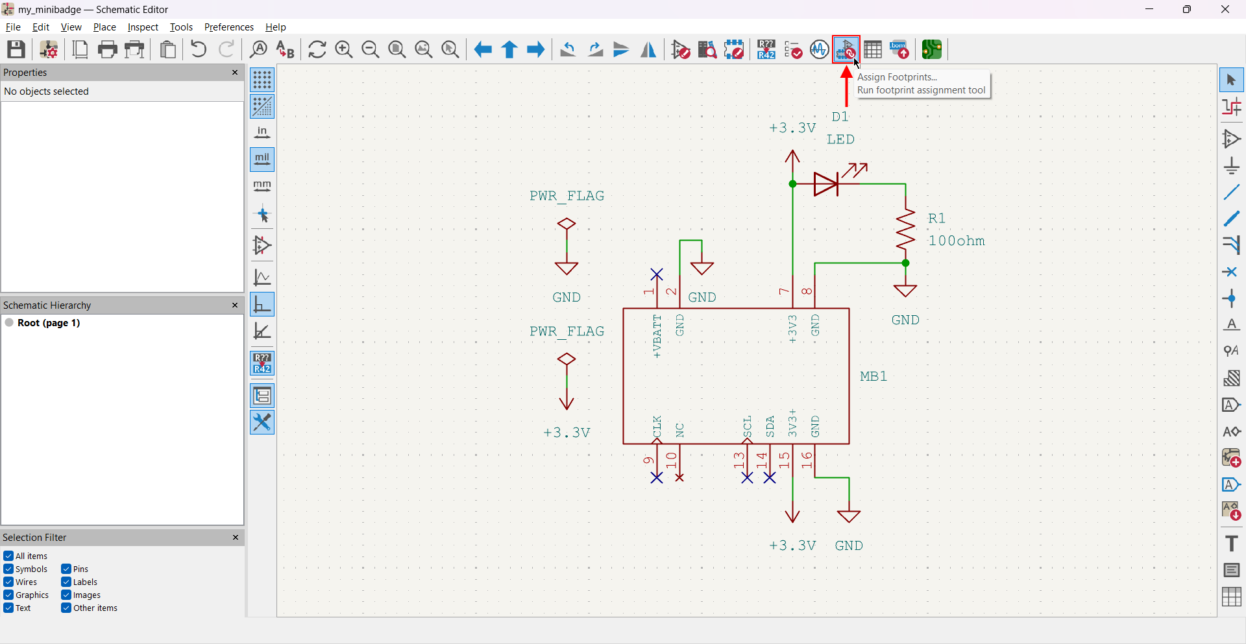
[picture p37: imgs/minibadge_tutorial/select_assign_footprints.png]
select assign footprints


A window will appear that will assist with assigning footprints to each part.
Footprints are the way that components will physically appear and connect to the board.
When picking footprints consider whether the part is SMD[^2] or THT[^3].
**Make sure the package[^4] matches the actual components.**
For this tutorial, footprints for a 5mm LED and a small through-hole resistor are used.

The exact footprint names used in this tutorial are the following:
D1: `LED_THT:LED_D5.0mm`
R1: `Resistor_THT:R_Axial_DIN0204_L3.6mm_D1.6mm_P5.08mm_Horizontal`

You can search for the exact components by typing in the text box to the right of the Footprint Filters section.

To assign a footprint, select the component you are assigning a footprint to (i.e. D1), and double click on an option from the Filtered Footprints sidebar.

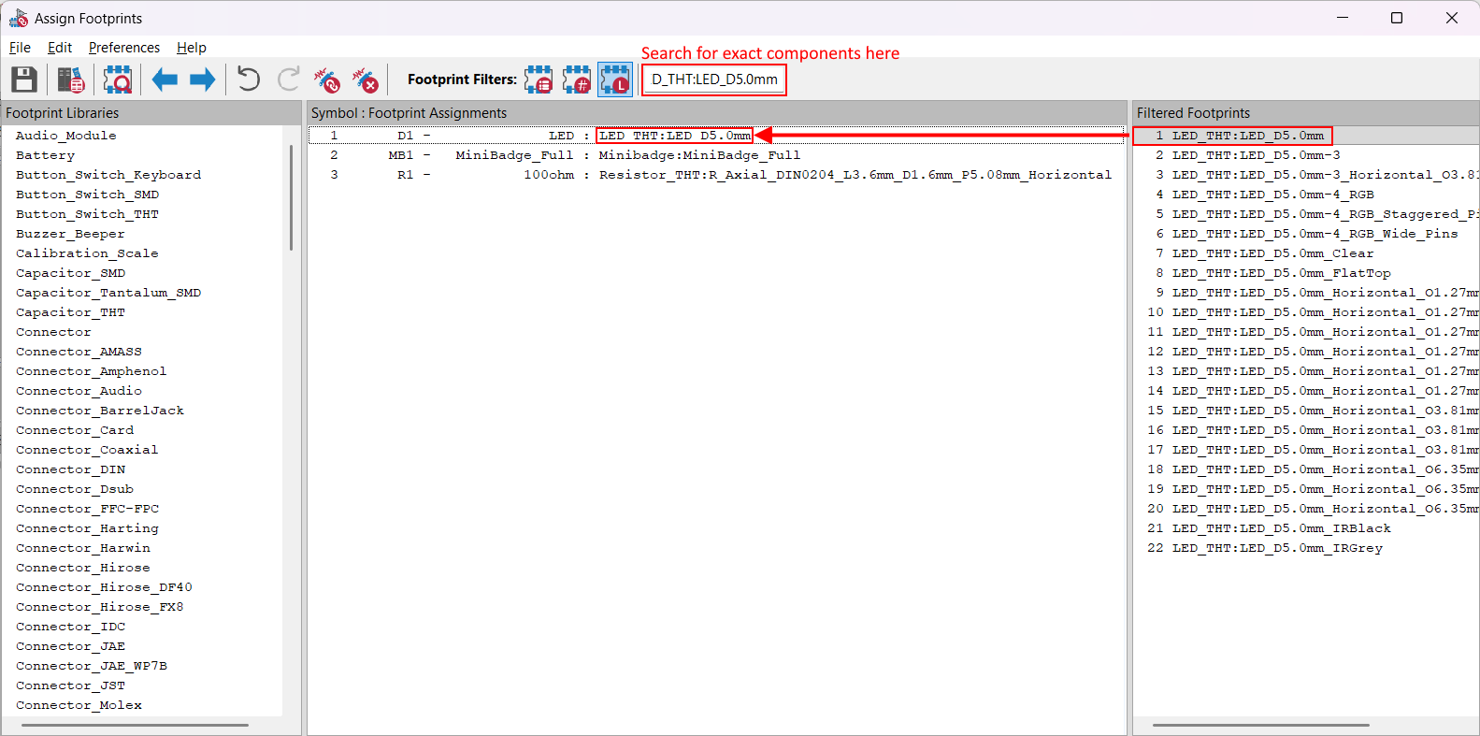
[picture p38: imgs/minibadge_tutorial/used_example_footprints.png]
used footprints


[^2]: *Surface-Mount Device.* These components are typically smaller and may be hard to solder by hand.
[^3]: *Through-Hole Technology.* These components are larger and typically easier to solder by hand.
[^4]: The package determines the physical dimensions of a device.
    For simple SMD devices, standard sizes may be used, such as 0603, or 1206.
    For THT devices, ensure the dimensions match or will be compatible.
    This involves verifying pitch between pins or other dimensions.
    **If a datasheet is available, these dimensions should be available and able to be matched with a KiCad footprint.**

Press the OK button.

The schematic portion is now complete. Save your project and close the schematic editor.

### PCB Layout

From the main window, enter the PCB editor by clicking on the icon.

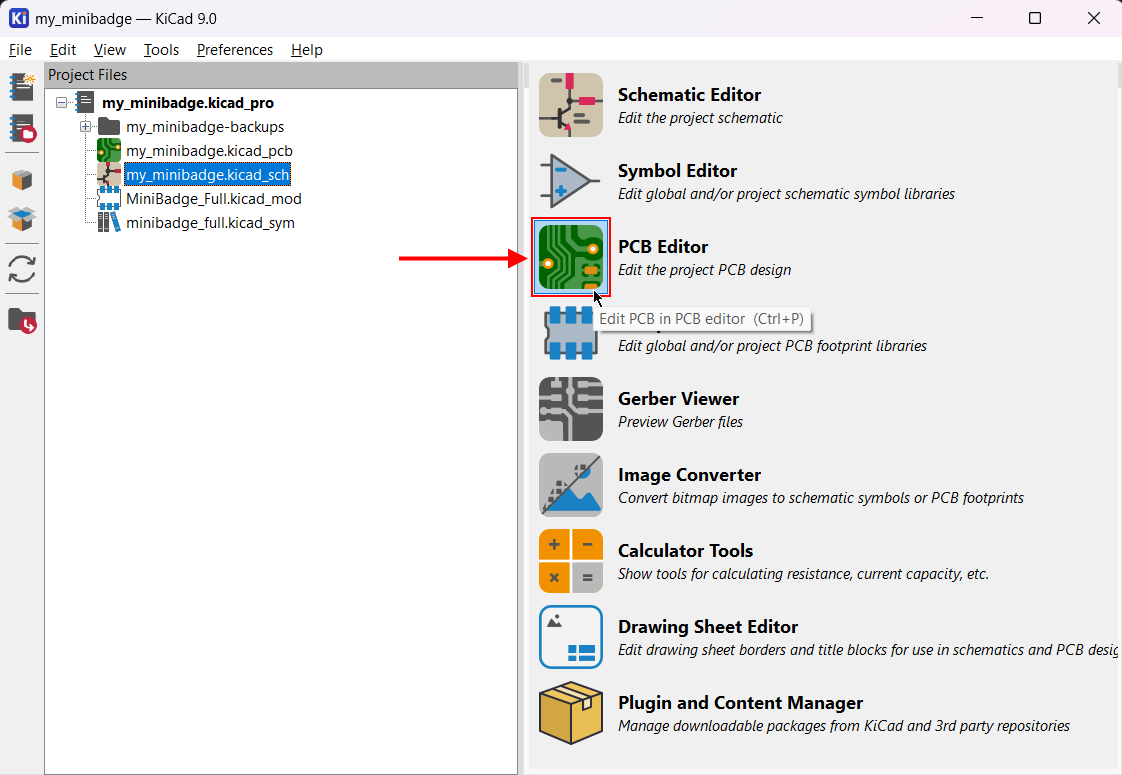
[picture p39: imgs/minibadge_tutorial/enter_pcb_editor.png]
select PCB editor


A blank PCB design will appear. Click the icon to update the PCB from the schematic or use the keyboard shortcut (F8).

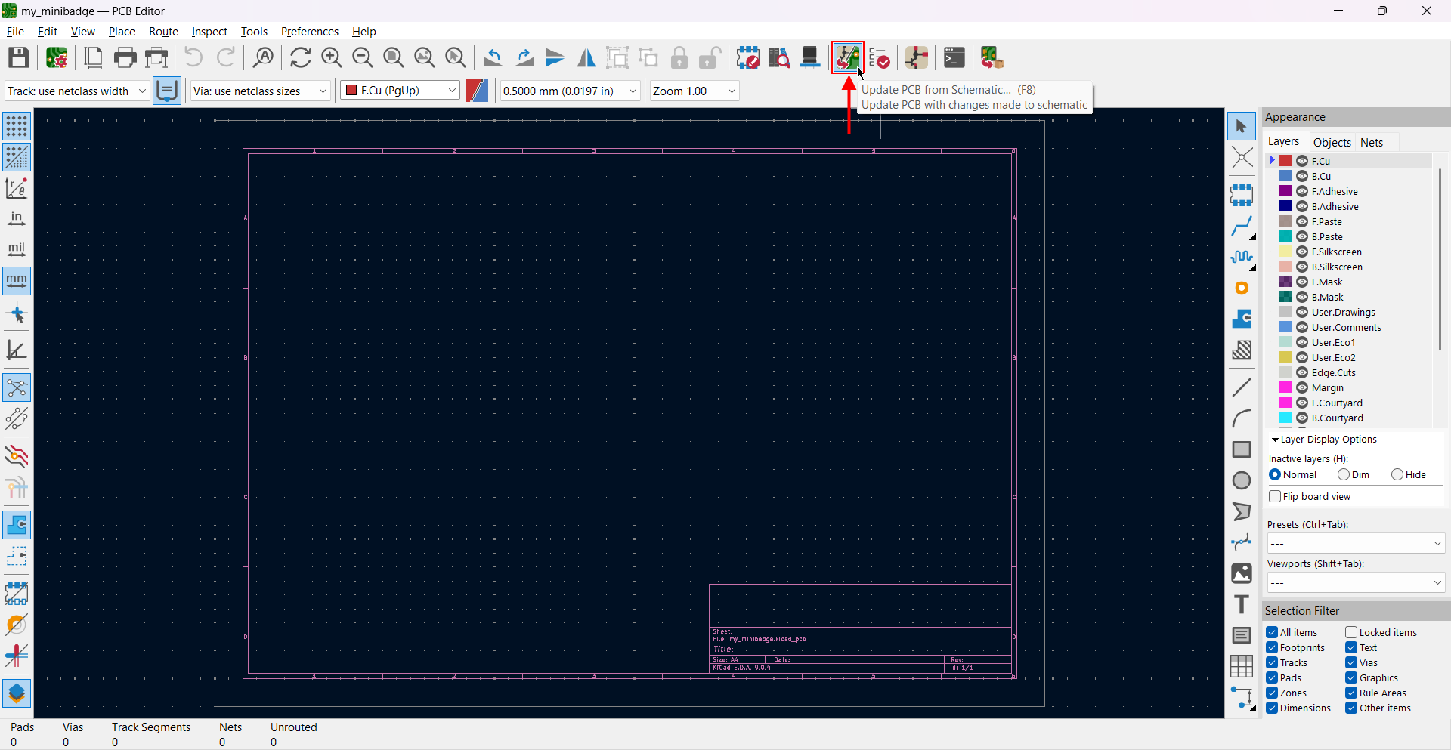
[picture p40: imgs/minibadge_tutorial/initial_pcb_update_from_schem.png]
select update PCB from schematic


A window will appear. Use the defaults and click `Update PCB`.

update PCB window

Components will appear on the PCB editor. Close the window an click near the center to place the mess of footprints.

see added footprints to place

Place the LED and resistor inside the minibadge footprint by clicking and dragging.
The resistor and LED should be placed on the back of the minibadge.
With the component selected, either:

1. Right click, then select `Change Side/Flip`.
2. Press `F`.

flip components hint

After arranging components, the design should appear similar to this:

example footprint placement

Again, note that the resistor and LED are placed on the back.
Minibadges typically are designed so that light can pass through the PCB.
In order for this to work, the design needs an area that prevents copper layers and soldermask from existing in a certain exclusion zone.

Click on the icon for drawing rule areas.

select draw rule area

Then, **very intentionally pick a point on the PCB that will be the starting point to draw a polygon for the rule area.**
After clicking a point on the PCB, a window will appear.
Select the copper layers and all relevant keepout rules.
**Do not select the footprint keepout rule because that will include the minibadge itself. Selecting it will cause errors later.**

rule area window

The default clearance rules are too strict for the minibadge and will throw errors. Fix this by entering the `Board Setup`.

select board setup

Select `Constraints` from the categories available. Then, set "Copper to edge clearance" to `0.35 mm`.
Press OK to close the window.

board setup window

Now that there are constraints and keepouts in place, areas for ground and power planes can be drawn.[^5]

[^5]: Normally, it is a bad idea to have a ground *and* a power plane on a two layer PCB.
    However, because there is only one connection other than power and ground and no rapid switching (like PWM signals),
    this is acceptable.
    Note that other designs may find it favorable to omit the power plane.

First, make sure a copper layer is selected.
Then, select the `Draw Filled Zones` tool, then select one of the corners of the PCB on or outside the `Edge.Cuts` layer.

select draw filled zones

After clicking the initial point to start the polygon drawing for the filled zone, a window will appear.
Select the front copper layer.
Select the `GND` net.
Optionally name the zone "Ground plane".
Press OK when finished.

ground plane properties window

After drawing the area for the ground plane, repeat the process for the power plane.
The power plane will reside on the rear copper layer.

power plane properties window

Press `B` to refill all copper zones. This will automatically route all connections for power and ground.

Only one connection remains. First, make sure you have the bottom copper layer selected (the power plane), and select the icon to `Route Single Track` or press the shortcut `X`.

The reason we want to have the power plane selected is to avoid splitting the ground plane. Not splitting the ground plane is generally considered good practice.

select route track

Click on one of the pads that has a faint line that connects two of them.
The design will appear to be faded, except for the track currently being routed.
Click on the other pad to connect the devices together.

draw track hint

Feel free to readjust the tracks.

Make sure to refill the zones so that the track is isolated from either plane.
Press `B` to refill all copper zones.

refill zone hint

A silkscreen design should be placed over the light passthrough window.
Designs can be made from images.
Go back to the main KiCad window without exiting the PCB editor, then select the icon for the image converter.

select image converter

A new window will open.
Select `Load Source Image` and navigate to the image that will be placed on the PCB silkscreen.

For this tutorial, any image will do, but the tutorial will use the [Github Pages QR code](../imgs/qr_code/main.png).

select load image source

The image will likely not fit within the desired dimension of the window on the PCB.
Return to the PCB editor.
Use the `Measure` tool to record the constraining dimension (whichever is smaller).

get dimensions of window hint

Return to the image converter window.
Make sure to dimension the image to fit in the window using the constraining dimension (height in this case).
If the source image isn't black and white, adjust the threshold and negative.
**Make sure the output format is a footprint on the `F.Silkscreen` layer.**
Press `Export to Clipboard` when done.

export image window

Return to the PCB editor.
Paste the image using `Ctrl+V` or right click and paste.
Click the place the silkscreen should reside.
An additional reference designator will be pasted alongside the image.
Select it, and press `Del` to delete it.

delete ref designator for vanity image

Light will not ideally escape through the light passthrough window yet.
Soldermask still will be applied over the window unless it is drawn over on the Mask layers.

Select the `F.Mask` layer then the `Draw Rectangles` tool.
After drawing the rectangle in the appropriate spot (over the rule area drawn earlier), select it.
Open the properties by right clicking and clicking `Properties` or using the shortcut key `E`.

select rectangle properties

In the properties, make the rectangle a filled shape.
Double check the layer is correct.

rectangle properties front window

Do the same process for the rear mask.
Ensure the properties are similar to the front mask, especially the filled shape property.

rectangle properties back window

Verify the design using the Design Rules Checker (DRC).
Click on the DRC icon.

select DRC

A new window will appear, much like the ERC when the schematic was checked. Select `Run DRC`.

**No errors should appear.**
There should be a warning for the intentionally placed silkscreen clipped by soldermask.
It can be safely ignored.

DRC safe warnings

# Export PCB for Fabrication

Navigate to the `Gerbers` fabrication output.

select gerber output

Ensure all needed layers are selected.
Select the output directory. Directories relative to the KiCad project are allowed.
After selecting the output directory, click `Plot` to generate the gerber files for each layer.
Afterward, select `Generate Drill Files`.

gerber plot window

Another window will appear on top of the plot window.
Ensure the output folder for the drill files is the same as the gerber output directory.
Then, select `Generate`.

generate drill window

Close the drill file generation window.
Navigate to the folder with the gerber and drill files.
The easiest way to do this is by using the icon to open the folder with the system file manager.

Use any method to zip all of the files in the directory to make a single output file.
This zipped file will be used for fabricating the actual PCB.

zip output files

These instructions assume using JLCPCB as a PCB manufacturer.
This process should be similar for other companies that do PCB fabrication.

On [jlcpcb.com](https://jlcpcb.com), upload the zip file containing your gerber and drill files.

JLCPCB upload

After a successful upload, a preview, cost estimate, and settings will appear.

preview JLCPCB

The most relevant settings for minibadge designs are:

* PCB Thickness
* PCB Color
* Silkscreen Color
* Mark on PCB

The thickness of the PCB affects parasitic capacitance.
Capacitance decreases inversely with thickness.

Assuming that FR-4 has a relative permittivity of 4.5:

| Thickness (mm) | A (mm^2)  | Capacitance (pF) |
| --- | --- | --- |
| 0.4 | 400 | 39.84 |
| 0.6 | 400 | 26.56 |
| 0.8 | 400 | 19.92 |
| 1.0 | 400 | 15.94 |
| 1.2 | 400 | 13.28 |
| 1.6 (Default)  | 400 | 9.96 |
| 2.0 | 400 | 7.97 |

The default thickness shouldn't cause problems.

Certain PCB colors may take longer to manufacture.

Make sure to select `Remove Mark` so that a JLCPCB order number doesn't appear on the minibadge.

JLCPCB order settings

Congratulations! You have finished designing your very own minibadge PCB! The minibadge PCB can now be ordered.

> [Go to Home](../README.md)

---

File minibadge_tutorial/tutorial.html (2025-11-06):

# Minibadge Tutorial

This tutorial is designed for KiCad 9.0.3. Download the latest version of KiCad from kicad.org (https://www.kicad.org/download/). A KiCad configuration with metric unit settings is assumed.

## Download Minibadge Symbols and Footprints

Navigate to github.com/BYU-I-eBadge/minibadge and go to the latest release.

minibadge GitHub page

The KiCad symbol and footprint variants can be found on the releases page. On the latest release¹, download minibadge_full.kicad_sym and MiniBadge_Full.kicad_mod for this tutorial. Save these in a folder that can be navigated to later.

minibadge release

## Design in KiCad

### Initial Project Setup

Make and open a new project in KiCad. Save it in a directory of your choice.

hint make new project

After making the new project, the symbol and footprint need to be added so they are accessible from library browsers. Navigate to Preferences on the toolbar.

go to preferences

Then, go to Manage Symbol Libraries.

go to manage symbol libraries

A new window will appear. Navigate to the Project Specific Libraries tab to add the Minibadge symbol to this project only.

switch tabs

Once switched to the correct tab, click the button with the folder icon to open the downloaded symbol library. For KiCad symbols, open the *.kicad_sym file to add the library.

add symbol library button point out symbol libraries are files

Press OK to save changes and close the window for managing symbol libraries. In preferences again, navigate to manage footprint libraries.

go to manage footprint libraries

Similar to the window for managing symbol libraries, navigate to the Project Specific Libraries tab. Click the button with the folder icon to open the downloaded footprint library. For KiCad footprints, open the folder that contains *.kicad_mod file(s) to add the library. This can reside in the same directory as your symbol library and other files; KiCad will only inventory the *.kicad_mod files from the selected folder.

add footprint library button point out footprint libraries are folders

### Schematic

Enter the schematic editor by pressing the icon in the main window.

hint enter schematic editor

A blank schematic will be shown. Start by placing symbols by pressing the highlighted icon or using the shortcut (A).

initial screen hint add symbol

Click anywhere on the schematic. A new window will appear that will allow for selecting symbols for components. Search for the minibadge symbol that was downloaded. Select the one that looks like the one pictured, and press OK to close the window.

select symbol window minibadge example

The symbol should appear attached to your cursor. Click to place the symbol. If the symbol still appears to follow your cursor after placement, press the ESC key to release your cursor; this is a side effect of having Place repeated copies selected.

symbol on schematic

For this tutorial, we will design a basic minibadge that has a simple LED circuit. Add symbols for an LED and resistor to the schematic by following a process similar to placing the minibadge.

add additional symbols

Now that all the symbols are placed, wires need to be added to connect the symbols together. Wire the LED anode (the side with the triangle base) to the +3V3 pin on the minibadge symbol. Wire the LED cathode (the side with the flat line) to any side of R1. Wire the unconnected side of R1 to the GND pin of the minibadge symbol. It is important that the circuit in your schematic is correct. It is easier to correct schematic issues before starting PCB design, rather than after.

add wire

For completeness, the circuit should have its used power paths (3.3V, Ground) labeled and attached to the schematic. Click on the icon to place power symbols or use the shortuct (P).

add power symbols

A window will appear that operates identical to picking symbols for components. For our ground (0V), use the GND symbol. Every pin that says GND on the minibadge should connect to one of these.

select ground symbol window

Similarly, power symbols should be placed for 3.3V. These should go on the pins labelled 3V3+ and +3V3.

select 3.3V symbol window

The schematic design is nearly complete. Click on the icon to place "no connect flags" on the remaining unused minibadge pins.

select no connect flags

Annotate the schematic so that the design can be checked for errors and be imported to the PCB editor.

select annotate schematic

Click Annotate on the window that appears. The default settings in this window should work for this design. Note that this overwrites all reference designators. This may not be ideal for different designs.

annotate window

Now that the schematic is fully annotated, the Electrical Rules Checker (ERC) should now be run.

select ERC

Click Run ERC on the window that appears.

run ERC

As of time of writing¹, running the ERC will result in certain warnings and errors that are safe to ignore. If there are additional errors, it is likely there is an actual error in the design that needs troubleshooting.

ERC false errors

After verifying the the design is electrically sound, click the icon to assign footprints to all symbols in the schematic.

select assign footprints

A window will appear that will assist with assigning footprints to each part. Footprints are the way that components will physically appear and connect to the board. When picking footprints consider whether the part is SMD² or THT³. Make sure the package⁴ matches the actual components. For this tutorial, footprints for a 5mm LED and small through-hole resistor are used.

used footprints

Save and close the schematic editor.

### PCB Layout

From the main window, enter the PCB editor by clicking on the icon.

select PCB editor

A blank PCB design will appear. Click the icon to update the PCB from the schematic or use the keyboard shortcut (F8).

select update PCB from schematic

A window will appear. Use the defaults and click Update PCB.

update PCB window

Components will appear on the PCB editor. Close the window an click near the center to place the mess of footprints.

see added footprints to place

Place the LED and resistor inside the minibadge footprint by clicking and dragging. The resistor and LED should be placed on the back of the minibadge. With the component selected, either:

1. Right click, then select Change Side/Flip.
2. Press F.

flip components hint

After arranging components, the design should appear similar to this:

example footprint placement

Again, note that the resistor and LED are placed on the back. Minibadges typically are designed so that light can pass through the PCB. In order for this to work, the design needs an area that prevents copper layers and soldermask from existing in a certain exclusion zone.

Click on the icon for drawing rule areas.

select draw rule area

Then, very intentionally pick a point on the PCB that will be the starting point to draw a polygon for the rule area. After clicking a point on the PCB, a window will appear. Select the copper layers and all relevant keepout rules. Do not select the footprint keepout rule because that will include the minibadge itself. Selecting it will cause errors later.

rule area window

The default clearance rules are too strict for the minibadge and will throw errors. Fix this by entering the Board Setup.

select board setup

Select Constraints from the categories available. Then, set "Copper to edge clearance" to 0.35 mm. Press OK to close the window.

board setup window

Now that there are constraints and keepouts in place, areas for ground and power planes can be drawn.⁵

First, make sure a copper layer is selected. Then, select the Draw Filled Zones tool, then select one of the corners of the PCB on or outside the Edge.Cuts layer.

select draw filled zones

After clicking the initial point to start the polygon drawing for the filled zone, a window will appear. Select the front copper layer. Select the GND net. Optionally name the zone "Ground plane". Press OK when finished.

ground plane properties window

After drawing the area for the ground plane, repeat the process for the power plane. The power plane will reside on the rear copper layer.

power plane properties window

Press B to refill all copper zones. This will automatically route all connections for power and ground.

Only one connection remains. Select the icon to Route Single Track or press the shortcut X.

select route track

Click on one of the pads that has a faint line that connects two of them. The design will appear to be faded, except for the track currently being routed. Click on the other pad to connect the devices together.

draw track hint

Make sure to refill the zones so that the track is isolated from either plane. Press B to refill all copper zones.

refill zone hint

A silkscreen design should be placed over the light passthrough window. Designs can be made from images. Go back to the main KiCad window without exiting the PCB editor, then select the icon for the image converter.

select image converter

A new window will open. Select Load Source Image and navigate to the image that will be placed on the PCB silkscreen.

select load image source

The image will likely not fit within the desired dimension of the window on the PCB. Return to the PCB editor. Use the Measure tool to record the constraining dimension (whichever is smaller).

get dimensions of window hint

Return to the image converter window. Make sure to dimension the image to fit in the window using the constraining dimension (height in this case). If the source image isn't black and white, adjust the threshold and negative. Make sure the output format is a footprint on the F.Silkscreen layer. Press Export to Clipboard when done.

export image window

Return to the PCB editor. Paste the image using Ctrl+V or right click and paste. Click the place the silkscreen should reside. An additional reference designator will be pasted alongside the image. Select it, and press Del to delete it.

delete ref designator for vanity image

Light will not ideally escape through the light passthrough window yet. Soldermask still will be applied over the window unless it is drawn over on the Mask layers.

Select the F.Mask layer then the Draw Rectangles tool. After drawing the rectangle in the appropriate spot (over the rule area drawn earlier), select it. Open the properties by right clicking and clicking Properties or using the shortcut key E.

select rectangle properties

In the properties, make the rectangle a filled shape. Double check the layer is correct.

rectangle properties front window

Do the same process for the rear mask. Ensure the properties are similar to the front mask, especially the filled shape property.

rectangle properties back window

Verify the design using the Design Rules Checker (DRC). Click on the DRC icon.

select DRC

A new window will appear. Select Run DRC.

DRC window

No errors should appear. There should be a warning for the intentionally placed silkscreen clipped by soldermask. It can be safely ignored.

DRC safe warnings

# Export PCB for Fabrication

Navigate to the Gerbers fabrication output.

select gerber output

Ensure all needed layers are selected. Select the output directory. Directories relative to the KiCad project are allowed. After selecting the output directory, click Plot to generate the gerber files for each layer. Afterward, select Generate Drill Files.

gerber plot window

Another window will appear on top of the plot window. Ensure the output folder for the drill files is the same as the gerber output directory. Then, select Generate.

generate drill window

Close the drill file generation window. Navigate to the folder with the gerber and drill files. The easiest way to do this is by using the icon to open the folder with the system file manager.

open directory shortcut

Use any method to zip all of the files in the directory to make a single output file. This zipped file will be used for fabricating the actual PCB.

zip output files

These instructions assume using JLCPCB as a PCB manufacturer. This process should be similar for other companies that do PCB fabrication.

On jlcpcb.com, upload the zip file containing your gerber and drill files.

JLCPCB upload

After a successful upload, a preview, cost estimate, and settings will appear.

preview JLCPCB

The most relevant settings for minibadge designs are:

- PCB Thickness
- PCB Color
- Silkscreen Color
- Mark on PCB

The thickness of the PCB affects parasitic capacitance. Capacitance decreases inversely with thickness.

Assuming that FR-4 has a relative permittivity of 4.5:

Thickness (mm) | A (mm^2) | Capacitance (pF)
0.4 | 400 | 39.84
0.6 | 400 | 26.56
0.8 | 400 | 19.92
1.0 | 400 | 15.94
1.2 | 400 | 13.28
1.6 (Default) | 400 | 9.96
2.0 | 400 | 7.97

The default thickness shouldn't cause problems.

Certain PCB colors may take longer to manufacture.

Make sure to select Remove Mark so that a JLCPCB order number doesn't appear on the minibadge.

JLCPCB order settings

The minibadge PCB can now be ordered.

1. 2025-07-21. Latest minibadge version 2.1c at time of writing. KiCad Version 9.0.3. Tutorial shown on Arch Linux/KDE Plasma. ↩↩
2. Surface-Mount Device. These components are typically smaller and may be hard to solder by hand. ↩
3. Through-Hole Technology. These components are larger and typically easier to solder by hand. ↩
4. The package determines the physical dimensions of a device. For simple SMD devices, standard sizes may be used, such as 0603, or 1206. For THT devices, ensure the dimensions match or will be compatible. This involves verifying pitch between pins or other dimensions. If a datasheet is available, these dimensions should be available and able to be matched with a KiCad footprint. ↩
5. Normally, it is a bad idea to have a ground and a power plane on a two layer PCB. However, because there is only one connection other than power and ground and no rapid switching (like PWM signals), this is acceptable. Note that other designs may find it favorable to omit the power plane. ↩

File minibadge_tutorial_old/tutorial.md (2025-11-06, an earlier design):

# Minibadge Tutorial

This tutorial is designed for KiCad 9.0.3.
Download the latest version of KiCad from [kicad.org](https://www.kicad.org/download/).
A KiCad configuration with metric unit settings is assumed.

## Download Minibadge Symbols and Footprints

Navigate to [github.com/BYU-I-eBadge/minibadge](https://github.com/BYU-I-eBadge/minibadge) and go to the latest release.

minibadge GitHub page

The KiCad symbol and footprint variants can be found on the releases page. On the latest release[^1], download `minibadge_full.kicad_sym` and `MiniBadge_Full.kicad_mod` for this tutorial. Save these in a folder that can be navigated to later.

minibadge release

## Design in KiCad

### Initial Project Setup

Make and open a new project in KiCad. Save it in a directory of your choice.

hint make new project

After making the new project, the symbol and footprint need to be added so they are accessible from library browsers. Navigate to `Preferences` on the toolbar.

go to preferences

Then, go to `Manage Symbol Libraries`.

go to manage symbol libraries

A new window will appear. Navigate to the `Project Specific Libraries` tab to add the Minibadge symbol to this project only.

switch tabs

Once switched to the correct tab, click the button with the folder icon to open the downloaded symbol library.
**For KiCad symbols, open the `*.kicad_sym` file to add the library.**

add symbol library button
point out symbol libraries are files

Press OK to save changes and close the window for managing symbol libraries. In preferences again, navigate to manage footprint libraries.

go to manage footprint libraries

Similar to the window for managing symbol libraries, navigate to the `Project Specific Libraries` tab.
Click the button with the folder icon to open the downloaded footprint library.
**For KiCad footprints, open the folder that contains `*.kicad_mod` file(s) to add the library. This can reside in the same directory as your symbol library and other files; KiCad will only inventory the `*.kicad_mod` files from the selected folder.**

add footprint library button
point out footprint libraries are folders

### Schematic

Enter the schematic editor by pressing the icon in the main window.

hint enter schematic editor

A blank schematic will be shown. Start by placing symbols by pressing the highlighted icon or using the shortcut (A).

initial screen hint add symbol

Click anywhere on the schematic. A new window will appear that will allow for selecting symbols for components.
Search for the minibadge symbol that was downloaded. Select the one that looks like the one pictured, and press OK to close the window.

select symbol window minibadge example

The symbol should appear attached to your cursor. Click to place the symbol. If the symbol still appears to follow your cursor after placement, press the ESC key to release your cursor; this is a side effect of having `Place repeated copies` selected.

symbol on schematic

For this tutorial, we will design a basic minibadge that has a simple LED circuit.
Add symbols for an LED and resistor to the schematic by following a process similar to placing the minibadge.

add additional symbols

Now that all the symbols are placed, wires need to be added to connect the symbols together.
Wire the LED anode (the side with the triangle base) to the `+3V3` pin on the minibadge symbol.
Wire the LED cathode (the side with the flat line) to any side of R1.
Wire the unconnected side of R1 to the GND pin of the minibadge symbol.
**It is important that the circuit in your schematic is correct. It is easier to correct schematic issues before starting PCB design, rather than after.**

add wire

For completeness, the circuit should have its used power paths (3.3V, Ground) labeled and attached to the schematic.
Click on the icon to place power symbols or use the shortuct (P).

add power symbols

A window will appear that operates identical to picking symbols for components.
For our ground (0V), use the `GND` symbol. Every pin that says `GND` on the minibadge should connect to one of these.

select ground symbol window

Similarly, power symbols should be placed for 3.3V. These should go on the pins labelled `3V3+` and `+3V3`.

select 3.3V symbol window

The schematic design is nearly complete. Click on the icon to place "no connect flags" on the remaining unused minibadge pins.

select no connect flags

Annotate the schematic so that the design can be checked for errors and be imported to the PCB editor.

select annotate schematic

Click `Annotate` on the window that appears. The default settings in this window should work for this design.
**Note that this overwrites all reference designators. This may not be ideal for different designs.**

annotate window

Now that the schematic is fully annotated, the Electrical Rules Checker (ERC) should now be run.

select ERC

Click `Run ERC` on the window that appears.

run ERC

As of time of writing[^1], running the ERC will result in certain warnings and errors that are safe to ignore.
**If there are additional errors, it is likely there is an actual error in the design that needs troubleshooting.**

[^1]: *2025-07-21*. Latest minibadge version 2.1c at time of writing. KiCad Version 9.0.3. Tutorial shown on Arch Linux/KDE Plasma.

ERC false errors

After verifying the the design is electrically sound, click the icon to assign footprints to all symbols in the schematic.

select assign footprints

A window will appear that will assist with assigning footprints to each part.
Footprints are the way that components will physically appear and connect to the board.
When picking footprints consider whether the part is SMD[^2] or THT[^3].
**Make sure the package[^4] matches the actual components.**
For this tutorial, footprints for a 5mm LED and small through-hole resistor are used.

[^2]: *Surface-Mount Device.* These components are typically smaller and may be hard to solder by hand.
[^3]: *Through-Hole Technology.* These components are larger and typically easier to solder by hand.
[^4]: The package determines the physical dimensions of a device.
    For simple SMD devices, standard sizes may be used, such as 0603, or 1206.
    For THT devices, ensure the dimensions match or will be compatible.
    This involves verifying pitch between pins or other dimensions.
    **If a datasheet is available, these dimensions should be available and able to be matched with a KiCad footprint.**

used footprints

Save and close the schematic editor.

### PCB Layout

From the main window, enter the PCB editor by clicking on the icon.

select PCB editor

A blank PCB design will appear. Click the icon to update the PCB from the schematic or use the keyboard shortcut (F8).

select update PCB from schematic

A window will appear. Use the defaults and click `Update PCB`.

update PCB window

Components will appear on the PCB editor. Close the window an click near the center to place the mess of footprints.

see added footprints to place

Place the LED and resistor inside the minibadge footprint by clicking and dragging.
The resistor and LED should be placed on the back of the minibadge.
With the component selected, either:

1. Right click, then select `Change Side/Flip`.
2. Press `F`.

flip components hint

After arranging components, the design should appear similar to this:

example footprint placement

Again, note that the resistor and LED are placed on the back.
Minibadges typically are designed so that light can pass through the PCB.
In order for this to work, the design needs an area that prevents copper layers and soldermask from existing in a certain exclusion zone.

Click on the icon for drawing rule areas.

select draw rule area

Then, **very intentionally pick a point on the PCB that will be the starting point to draw a polygon for the rule area.**
After clicking a point on the PCB, a window will appear.
Select the copper layers and all relevant keepout rules.
**Do not select the footprint keepout rule because that will include the minibadge itself. Selecting it will cause errors later.**

rule area window

The default clearance rules are too strict for the minibadge and will throw errors. Fix this by entering the `Board Setup`.

select board setup

Select `Constraints` from the categories available. Then, set "Copper to edge clearance" to `0.35 mm`.
Press OK to close the window.

board setup window

Now that there are constraints and keepouts in place, areas for ground and power planes can be drawn.[^5]

[^5]: Normally, it is a bad idea to have a ground *and* a power plane on a two layer PCB.
    However, because there is only one connection other than power and ground and no rapid switching (like PWM signals),
    this is acceptable.
    Note that other designs may find it favorable to omit the power plane.

First, make sure a copper layer is selected.
Then, select the `Draw Filled Zones` tool, then select one of the corners of the PCB on or outside the `Edge.Cuts` layer.

select draw filled zones

After clicking the initial point to start the polygon drawing for the filled zone, a window will appear.
Select the front copper layer.
Select the `GND` net.
Optionally name the zone "Ground plane".
Press OK when finished.

ground plane properties window

After drawing the area for the ground plane, repeat the process for the power plane.
The power plane will reside on the rear copper layer.

power plane properties window

Press `B` to refill all copper zones. This will automatically route all connections for power and ground.

Only one connection remains. Select the icon to `Route Single Track` or press the shortcut `X`.

select route track

Click on one of the pads that has a faint line that connects two of them.
The design will appear to be faded, except for the track currently being routed.
Click on the other pad to connect the devices together.

draw track hint

Make sure to refill the zones so that the track is isolated from either plane.
Press `B` to refill all copper zones.

refill zone hint

A silkscreen design should be placed over the light passthrough window.
Designs can be made from images.
Go back to the main KiCad window without exiting the PCB editor, then select the icon for the image converter.

select image converter

A new window will open.
Select `Load Source Image` and navigate to the image that will be placed on the PCB silkscreen.

select load image source

The image will likely not fit within the desired dimension of the window on the PCB.
Return to the PCB editor.
Use the `Measure` tool to record the constraining dimension (whichever is smaller).

get dimensions of window hint

Return to the image converter window.
Make sure to dimension the image to fit in the window using the constraining dimension (height in this case).
If the source image isn't black and white, adjust the threshold and negative.
**Make sure the output format is a footprint on the `F.Silkscreen` layer.**
Press `Export to Clipboard` when done.

export image window

Return to the PCB editor.
Paste the image using `Ctrl+V` or right click and paste.
Click the place the silkscreen should reside.
An additional reference designator will be pasted alongside the image.
Select it, and press `Del` to delete it.

delete ref designator for vanity image

Light will not ideally escape through the light passthrough window yet.
Soldermask still will be applied over the window unless it is drawn over on the Mask layers.

Select the `F.Mask` layer then the `Draw Rectangles` tool.
After drawing the rectangle in the appropriate spot (over the rule area drawn earlier), select it.
Open the properties by right clicking and clicking `Properties` or using the shortcut key `E`.

select rectangle properties

In the properties, make the rectangle a filled shape.
Double check the layer is correct.

rectangle properties front window

Do the same process for the rear mask.
Ensure the properties are similar to the front mask, especially the filled shape property.

rectangle properties back window

Verify the design using the Design Rules Checker (DRC).
Click on the DRC icon.

select DRC

A new window will appear.
Select `Run DRC`.

DRC window

**No errors should appear.**
There should be a warning for the intentionally placed silkscreen clipped by soldermask.
It can be safely ignored.

DRC safe warnings

# Export PCB for Fabrication

Navigate to the `Gerbers` fabrication output.

select gerber output

Ensure all needed layers are selected.
Select the output directory. Directories relative to the KiCad project are allowed.
After selecting the output directory, click `Plot` to generate the gerber files for each layer.
Afterward, select `Generate Drill Files`.

gerber plot window

Another window will appear on top of the plot window.
Ensure the output folder for the drill files is the same as the gerber output directory.
Then, select `Generate`.

generate drill window

Close the drill file generation window.
Navigate to the folder with the gerber and drill files.
The easiest way to do this is by using the icon to open the folder with the system file manager.

open directory shortcut

Use any method to zip all of the files in the directory to make a single output file.
This zipped file will be used for fabricating the actual PCB.

zip output files

These instructions assume using JLCPCB as a PCB manufacturer.
This process should be similar for other companies that do PCB fabrication.

On [jlcpcb.com](https://jlcpcb.com), upload the zip file containing your gerber and drill files.

JLCPCB upload

After a successful upload, a preview, cost estimate, and settings will appear.

preview JLCPCB

The most relevant settings for minibadge designs are:

* PCB Thickness
* PCB Color
* Silkscreen Color
* Mark on PCB

The thickness of the PCB affects parasitic capacitance.
Capacitance decreases inversely with thickness.

Assuming that FR-4 has a relative permittivity of 4.5:

| Thickness (mm) | A (mm^2)  | Capacitance (pF) |
| --- | --- | --- |
| 0.4 | 400 | 39.84 |
| 0.6 | 400 | 26.56 |
| 0.8 | 400 | 19.92 |
| 1.0 | 400 | 15.94 |
| 1.2 | 400 | 13.28 |
| 1.6 (Default)  | 400 | 9.96 |
| 2.0 | 400 | 7.97 |

The default thickness shouldn't cause problems.

Certain PCB colors may take longer to manufacture.

Make sure to select `Remove Mark` so that a JLCPCB order number doesn't appear on the minibadge.

JLCPCB order settings

The minibadge PCB can now be ordered.

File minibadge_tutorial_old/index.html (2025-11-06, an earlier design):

# Minibadge Tutorial

This tutorial is designed for KiCad 9.0.3. Download the latest version of KiCad from kicad.org (https://www.kicad.org/download/). A KiCad configuration with metric unit settings is assumed.

## Download Minibadge Symbols and Footprints

Navigate to github.com/BYU-I-eBadge/minibadge and go to the latest release.

minibadge GitHub page

The KiCad symbol and footprint variants can be found on the releases page. On the latest release¹, download minibadge_full.kicad_sym and MiniBadge_Full.kicad_mod for this tutorial. Save these in a folder that can be navigated to later.

minibadge release

## Design in KiCad

### Initial Project Setup

Make and open a new project in KiCad. Save it in a directory of your choice.

hint make new project

After making the new project, the symbol and footprint need to be added so they are accessible from library browsers. Navigate to Preferences on the toolbar.

go to preferences

Then, go to Manage Symbol Libraries.

go to manage symbol libraries

A new window will appear. Navigate to the Project Specific Libraries tab to add the Minibadge symbol to this project only.

switch tabs

Once switched to the correct tab, click the button with the folder icon to open the downloaded symbol library. For KiCad symbols, open the *.kicad_sym file to add the library.

add symbol library button point out symbol libraries are files

Press OK to save changes and close the window for managing symbol libraries. In preferences again, navigate to manage footprint libraries.

go to manage footprint libraries

Similar to the window for managing symbol libraries, navigate to the Project Specific Libraries tab. Click the button with the folder icon to open the downloaded footprint library. For KiCad footprints, open the folder that contains *.kicad_mod file(s) to add the library. This can reside in the same directory as your symbol library and other files; KiCad will only inventory the *.kicad_mod files from the selected folder.

add footprint library button point out footprint libraries are folders

### Schematic

Enter the schematic editor by pressing the icon in the main window.

hint enter schematic editor

A blank schematic will be shown. Start by placing symbols by pressing the highlighted icon or using the shortcut (A).

initial screen hint add symbol

Click anywhere on the schematic. A new window will appear that will allow for selecting symbols for components. Search for the minibadge symbol that was downloaded. Select the one that looks like the one pictured, and press OK to close the window.

select symbol window minibadge example

The symbol should appear attached to your cursor. Click to place the symbol. If the symbol still appears to follow your cursor after placement, press the ESC key to release your cursor; this is a side effect of having Place repeated copies selected.

symbol on schematic

For this tutorial, we will design a basic minibadge that has a simple LED circuit. Add symbols for an LED and resistor to the schematic by following a process similar to placing the minibadge.

add additional symbols

Now that all the symbols are placed, wires need to be added to connect the symbols together. Wire the LED anode (the side with the triangle base) to the +3V3 pin on the minibadge symbol. Wire the LED cathode (the side with the flat line) to any side of R1. Wire the unconnected side of R1 to the GND pin of the minibadge symbol. It is important that the circuit in your schematic is correct. It is easier to correct schematic issues before starting PCB design, rather than after.

add wire

For completeness, the circuit should have its used power paths (3.3V, Ground) labeled and attached to the schematic. Click on the icon to place power symbols or use the shortuct (P).

add power symbols

A window will appear that operates identical to picking symbols for components. For our ground (0V), use the GND symbol. Every pin that says GND on the minibadge should connect to one of these.

select ground symbol window

Similarly, power symbols should be placed for 3.3V. These should go on the pins labelled 3V3+ and +3V3.

select 3.3V symbol window

The schematic design is nearly complete. Click on the icon to place "no connect flags" on the remaining unused minibadge pins.

select no connect flags

Annotate the schematic so that the design can be checked for errors and be imported to the PCB editor.

select annotate schematic

Click Annotate on the window that appears. The default settings in this window should work for this design. Note that this overwrites all reference designators. This may not be ideal for different designs.

annotate window

Now that the schematic is fully annotated, the Electrical Rules Checker (ERC) should now be run.

select ERC

Click Run ERC on the window that appears.

run ERC

As of time of writing¹, running the ERC will result in certain warnings and errors that are safe to ignore. If there are additional errors, it is likely there is an actual error in the design that needs troubleshooting.

ERC false errors

After verifying the the design is electrically sound, click the icon to assign footprints to all symbols in the schematic.

select assign footprints

A window will appear that will assist with assigning footprints to each part. Footprints are the way that components will physically appear and connect to the board. When picking footprints consider whether the part is SMD² or THT³. Make sure the package⁴ matches the actual components. For this tutorial, footprints for a 5mm LED and small through-hole resistor are used.

used footprints

Save and close the schematic editor.

### PCB Layout

From the main window, enter the PCB editor by clicking on the icon.

select PCB editor

A blank PCB design will appear. Click the icon to update the PCB from the schematic or use the keyboard shortcut (F8).

select update PCB from schematic

A window will appear. Use the defaults and click Update PCB.

update PCB window

Components will appear on the PCB editor. Close the window an click near the center to place the mess of footprints.

see added footprints to place

Place the LED and resistor inside the minibadge footprint by clicking and dragging. The resistor and LED should be placed on the back of the minibadge. With the component selected, either:

1. Right click, then select Change Side/Flip.
2. Press F.

flip components hint

After arranging components, the design should appear similar to this:

example footprint placement

Again, note that the resistor and LED are placed on the back. Minibadges typically are designed so that light can pass through the PCB. In order for this to work, the design needs an area that prevents copper layers and soldermask from existing in a certain exclusion zone.

Click on the icon for drawing rule areas.

select draw rule area

Then, very intentionally pick a point on the PCB that will be the starting point to draw a polygon for the rule area. After clicking a point on the PCB, a window will appear. Select the copper layers and all relevant keepout rules. Do not select the footprint keepout rule because that will include the minibadge itself. Selecting it will cause errors later.

rule area window

The default clearance rules are too strict for the minibadge and will throw errors. Fix this by entering the Board Setup.

select board setup

Select Constraints from the categories available. Then, set "Copper to edge clearance" to 0.35 mm. Press OK to close the window.

board setup window

Now that there are constraints and keepouts in place, areas for ground and power planes can be drawn.⁵

First, make sure a copper layer is selected. Then, select the Draw Filled Zones tool, then select one of the corners of the PCB on or outside the Edge.Cuts layer.

select draw filled zones

After clicking the initial point to start the polygon drawing for the filled zone, a window will appear. Select the front copper layer. Select the GND net. Optionally name the zone "Ground plane". Press OK when finished.

ground plane properties window

After drawing the area for the ground plane, repeat the process for the power plane. The power plane will reside on the rear copper layer.

power plane properties window

Press B to refill all copper zones. This will automatically route all connections for power and ground.

Only one connection remains. Select the icon to Route Single Track or press the shortcut X.

select route track

Click on one of the pads that has a faint line that connects two of them. The design will appear to be faded, except for the track currently being routed. Click on the other pad to connect the devices together.

draw track hint

Make sure to refill the zones so that the track is isolated from either plane. Press B to refill all copper zones.

refill zone hint

A silkscreen design should be placed over the light passthrough window. Designs can be made from images. Go back to the main KiCad window without exiting the PCB editor, then select the icon for the image converter.

select image converter

A new window will open. Select Load Source Image and navigate to the image that will be placed on the PCB silkscreen.

select load image source

The image will likely not fit within the desired dimension of the window on the PCB. Return to the PCB editor. Use the Measure tool to record the constraining dimension (whichever is smaller).

get dimensions of window hint

Return to the image converter window. Make sure to dimension the image to fit in the window using the constraining dimension (height in this case). If the source image isn't black and white, adjust the threshold and negative. Make sure the output format is a footprint on the F.Silkscreen layer. Press Export to Clipboard when done.

export image window

Return to the PCB editor. Paste the image using Ctrl+V or right click and paste. Click the place the silkscreen should reside. An additional reference designator will be pasted alongside the image. Select it, and press Del to delete it.

delete ref designator for vanity image

Light will not ideally escape through the light passthrough window yet. Soldermask still will be applied over the window unless it is drawn over on the Mask layers.

Select the F.Mask layer then the Draw Rectangles tool. After drawing the rectangle in the appropriate spot (over the rule area drawn earlier), select it. Open the properties by right clicking and clicking Properties or using the shortcut key E.

select rectangle properties

In the properties, make the rectangle a filled shape. Double check the layer is correct.

rectangle properties front window

Do the same process for the rear mask. Ensure the properties are similar to the front mask, especially the filled shape property.

rectangle properties back window

Verify the design using the Design Rules Checker (DRC). Click on the DRC icon.

select DRC

A new window will appear. Select Run DRC.

DRC window

No errors should appear. There should be a warning for the intentionally placed silkscreen clipped by soldermask. It can be safely ignored.

DRC safe warnings

# Export PCB for Fabrication

Navigate to the Gerbers fabrication output.

select gerber output

Ensure all needed layers are selected. Select the output directory. Directories relative to the KiCad project are allowed. After selecting the output directory, click Plot to generate the gerber files for each layer. Afterward, select Generate Drill Files.

gerber plot window

Another window will appear on top of the plot window. Ensure the output folder for the drill files is the same as the gerber output directory. Then, select Generate.

generate drill window

Close the drill file generation window. Navigate to the folder with the gerber and drill files. The easiest way to do this is by using the icon to open the folder with the system file manager.

open directory shortcut

Use any method to zip all of the files in the directory to make a single output file. This zipped file will be used for fabricating the actual PCB.

zip output files

These instructions assume using JLCPCB as a PCB manufacturer. This process should be similar for other companies that do PCB fabrication.

On jlcpcb.com, upload the zip file containing your gerber and drill files.

JLCPCB upload

After a successful upload, a preview, cost estimate, and settings will appear.

preview JLCPCB

The most relevant settings for minibadge designs are:

- PCB Thickness
- PCB Color
- Silkscreen Color
- Mark on PCB

The thickness of the PCB affects parasitic capacitance. Capacitance decreases inversely with thickness.

Assuming that FR-4 has a relative permittivity of 4.5:

Thickness (mm) | A (mm^2) | Capacitance (pF)
0.4 | 400 | 39.84
0.6 | 400 | 26.56
0.8 | 400 | 19.92
1.0 | 400 | 15.94
1.2 | 400 | 13.28
1.6 (Default) | 400 | 9.96
2.0 | 400 | 7.97

The default thickness shouldn't cause problems.

Certain PCB colors may take longer to manufacture.

Make sure to select Remove Mark so that a JLCPCB order number doesn't appear on the minibadge.

JLCPCB order settings

The minibadge PCB can now be ordered.

1. 2025-07-21. Latest minibadge version 2.1c at time of writing. KiCad Version 9.0.3. Tutorial shown on Arch Linux/KDE Plasma. ↩↩
2. Surface-Mount Device. These components are typically smaller and may be hard to solder by hand. ↩
3. Through-Hole Technology. These components are larger and typically easier to solder by hand. ↩
4. The package determines the physical dimensions of a device. For simple SMD devices, standard sizes may be used, such as 0603, or 1206. For THT devices, ensure the dimensions match or will be compatible. This involves verifying pitch between pins or other dimensions. If a datasheet is available, these dimensions should be available and able to be matched with a KiCad footprint. ↩
5. Normally, it is a bad idea to have a ground and a power plane on a two layer PCB. However, because there is only one connection other than power and ground and no rapid switching (like PWM signals), this is acceptable. Note that other designs may find it favorable to omit the power plane. ↩

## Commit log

2025-11-16 Update README.md
    Add links to repositories and current minibadge tutorial.
2025-11-17 Implement Minibadge LED Tutorial
    Added Minibadge LED Tutorial, and updated it up to the schematic.
    TODO:
    Update the Schematic section
    Update the PCB section
    Update the JLCPCB purchase section
2025-11-24 Added Example Projects
    Added example minibadge projects from the tutorials and other assets.
    [bom.csv, designators.csv, i2c_flash_minibadge.kicad_pcb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]
2025-12-01 Finish LED Tutorial
    See summary.
2026-03-09 Add tetris_game v1.0.0 binary (landscape ILI9341, ESP32-S3)
2026-04-05 Adding Arduino support
2026-04-05 Release BYUI-Namebadge-Board v1.0.15
2026-04-06 Rename 'Demo Programs' to 'Power-On Demos'
2026-05-02 Pin Power-On Demos to bottom of program dropdown
2026-05-08 Tetris v3: level-1 drop speed 960ms→720ms (base 60→45 ticks)
